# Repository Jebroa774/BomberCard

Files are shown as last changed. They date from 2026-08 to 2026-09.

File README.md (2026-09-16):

# BomberCard V1

<p align="center">
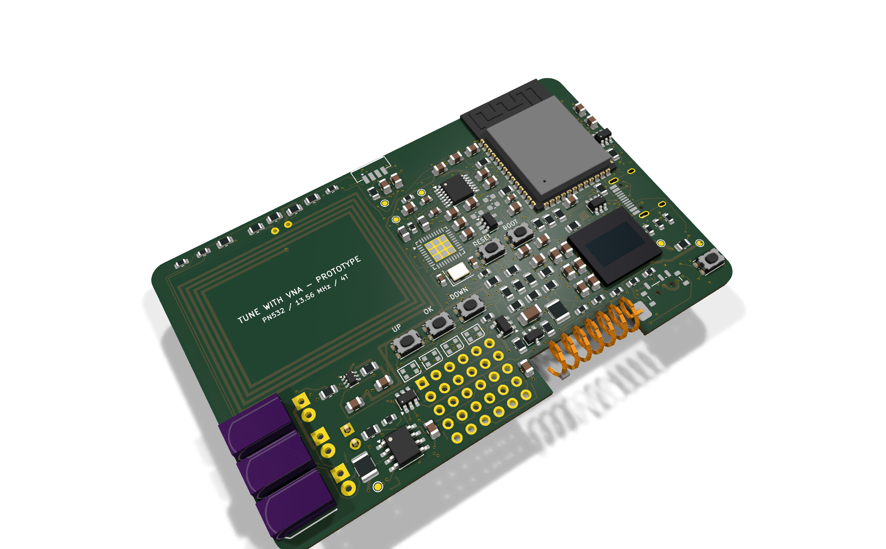
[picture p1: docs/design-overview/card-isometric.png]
BomberCard V1 current KiCad isometric view
  
</p>

BomberCard V1 is an original, credit-card-outline ESP32-S3 field tool with
Wi-Fi/BLE control, NFC, LF RFID, Sub-GHz, infrared, removable storage and a
small local user interface. The hardware is designed around a four-layer PCB,
a single-cell LiPo supply and parts that can be assembled by JLCPCB or fitted by
hand where practical.

> [!NOTE]
> **Proudly vibe-coded.** The project grows through hands-on experimentation,
> rapid idea-driven iteration and AI-assisted engineering. Here, vibe coding
> does not mean blindly trusting generated output: the hardware remains an
> engineering prototype until its schematic, PCB, DRC/DFM results and physical
> measurements have been independently checked.

> [!WARNING]
> **Engineering prototype — not ready to order.** The current authoritative
> board has 33 open connection items. KiCad reports 0 geometric/electrical DRC
> violations; the 7 remaining report entries are footprint-library comparison
> notices. Routing completion, DFM review, RF/LF tuning, sourcing review and
> prototype measurements remain required before fabrication.

## Current hardware

| Area | V1 implementation |
|---|---|
| Controller | ESP32-S3-WROOM-1-N8R2 with native USB, Wi-Fi and BLE |
| 13.56 MHz NFC | PN532 with a project-local 35 x 27 mm four-turn PCB antenna |
| 125 kHz LF RFID | HTRC110 front end with a removable, measurable and tuneable coil |
| Sub-GHz | E07-900MM10S/CC1101 module, tuneable pi network and inboard 868 MHz spring antenna |
| Infrared | Three independent high-power 940 nm emitters plus a 38 kHz receiver |
| Storage and security | microSD, ATECC608C secure element and physical PAIR button |
| User interface | Four RGB LEDs, UP/SELECT/DOWN controls and a firmware-configurable AUX button |
| Sensors | Optional 6-axis IMU, barometer, RTC, fuel gauge and board-temperature monitor |
| Power | USB-C, 1-cell LiPo input, charging/power path, regulated 3.3 V and switchable 5 V |
| Expansion | Protected 2.54 mm breakout matrix with eleven direct expansion GPIOs |

The **ESP32-S3 remains the controller for V1**. The newer ESP32-S31 is being
kept as a possible V2 candidate, but its preliminary hardware ecosystem,
larger WROOM module and immature availability do not justify restarting this
layout.

## Current PCB views

The following images were generated from the current KiCad routing checkpoint.
The hand-fitted IR bodies and spring antenna use approximate preview models;
footprints, courtyards and the PCB outline remain the mechanical references.

<table>
  <tr>
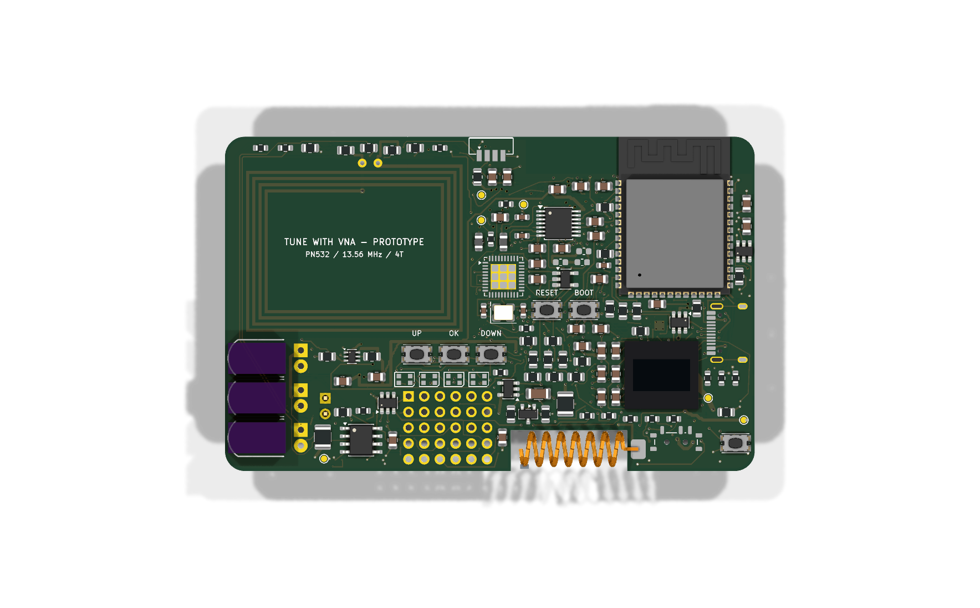
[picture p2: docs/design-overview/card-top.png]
Current PCB top view
    <td align="center"><br><strong>Top</strong></td>
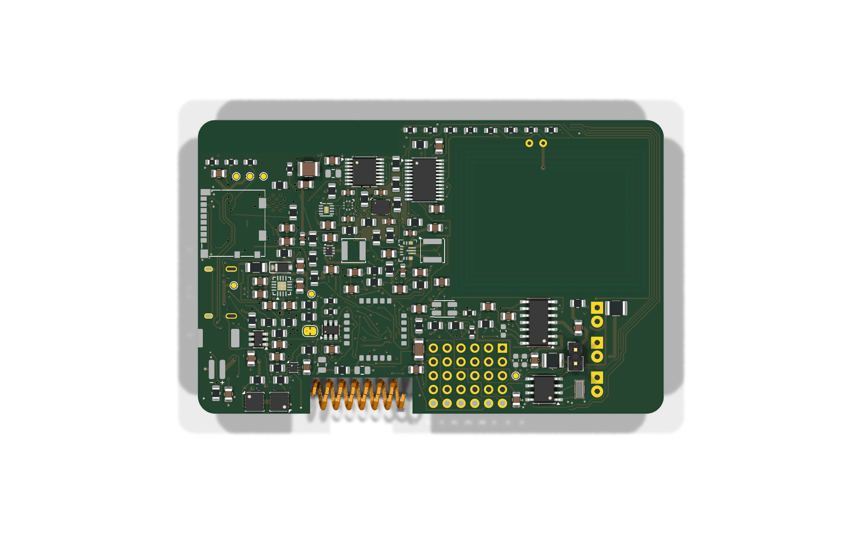
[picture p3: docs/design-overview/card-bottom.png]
Current PCB bottom view
    <td align="center"><br><strong>Bottom</strong></td>
  </tr>
</table>

More layout and enclosure notes are available in the
[design overview](docs/design-overview/README.md). An interactive WebGL view is
available as the
[live BomberCard 3D Viewer](https://jebroa774.github.io/BomberCard/).
Its source is stored in
[`docs/design-overview/viewer.html`](docs/design-overview/viewer.html).

## Mechanical target

- 85.60 x 53.98 mm credit-card outline with rounded corners
- Four-layer, nominal 1.2 mm FR-4 using the JLC04121H-7628 stack target
- 1 oz outer and 0.5 oz inner copper with ENIG finish
- Components on both sides; approximately 8–9 mm provisional assembled height
- Three inboard edge-facing IR emitters and an inboard spring-antenna pocket
- Compact unpopulated 6 x 5 matrix of 30 holes on 2.54 mm pitch
- Initial bring-up quantity: five assembled prototype boards

This is a credit-card-shaped instrument, not a wallet-thickness card. The final
height and enclosure clearances must be verified against received components.

## Engineering status

| Check | Current result |
|---|---:|
| Schematic symbols | 274 |
| Assigned footprints | 267 |
| Named logical nets | 181 |
| Physical PCB nets | 231 |
| ERC | 0 errors / 0 warnings |
| Placed footprints | 264 |
| Routed checkpoint | 4863 track segments / 1019 vias / 24 zones |
| Remaining connection items | 33 |
| Geometric/electrical DRC findings | 0 |
| Footprint-library comparison notices | 7 |

Completed design work includes the full schematic, mechanical placement,
four-layer stack definition, native USB pair, local converter routes, RTC
crystal routes, the provisional Sub-GHz feed/pi network and the via-free
back-side LF RFID analog island. The active PCB work is closing the final 33
routing connections while preserving the current zero-error DRC baseline.

### Before the first PCB order

- Confirm the live JLCPCB stack and recalculate USB/Sub-GHz geometry.
- Review the completed LF/NFC and digital routing against the schematic.
- Finish DRC cleanup, ground stitching and plane review.
- Re-run final KiCad DRC/parity checks from a clean checkout.
- Review every footprint, BOM and placement entry against current supplier data.
- Reconfirm PN532 availability because the part is NRND, and qualify an
  alternative before any production revision.
- Inspect the JLCPCB DFM, BOM and CPL previews and obtain an independent review.
- Tune NFC, LF RFID and Sub-GHz on the assembled prototypes with suitable test
  equipment before treating any RF values as production-ready.

The detailed hand-off state is maintained in the
[work checkpoint](docs/work-checkpoint.md).

## Repository layout

```text
BomberCard/
|-- docs/           Architecture, constraints, checkpoints and current renders
|-- hardware/       KiCad source, local libraries, reports and layout helpers
|-- firmware/       ESP32-S3 firmware source and board configuration
`-- manufacturing/  Fabrication/assembly generation tools and future releases
```

Open `hardware/PocketLab-Card.kicad_pro` in KiCad 10 for the complete project.
The tracked `hardware/PocketLab-Card.kicad_pcb` is the current routing-in-progress
board, not a fabrication release.

## Responsible use

RF, RFID/NFC and infrared functions are intended only for devices, systems,
frequencies, antennas, output levels and duty cycles the operator is legally
permitted to use. Prototype RF performance, electromagnetic compatibility and
regulatory compliance have not yet been verified.

The project is original and does not copy SGP branding, artwork, PCB layout or
firmware.

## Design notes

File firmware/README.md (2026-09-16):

# BomberCard firmware

Buildable ESP32-S3 bring-up firmware for hardware revision 1. It targets the
ESP32-S3-WROOM-1-N8R2 with Arduino-ESP32 3.x and PlatformIO.

## Implemented baseline

- WPA2 Wi-Fi SoftAP, REST API, read-only WebSocket status and mobile web UI
- microSD mount, listing, download, upload, deletion and remount
- safe boot states for CC1101, microSD, IR, RGB, LF RFID and exposed GPIOs
- read-only CC1101 identity, PN532 presence and both I/O-expander probes
- HTRC110 5 V power sequencing, three-wire command transport, configuration
  readback, phase/sampling setup and antenna-failure diagnosis
- ATECC608C wake/presence probe without changing or locking its configuration
- physical PAIR-button gate for a 60-second pairing window
- bounded NEC IR transmission through the three emitters
- 16-sample GPIO9 board-NTC measurement, web status and 80-degree-C thermal
  shutdown of charging and 5-V loads with 70-degree-C release hysteresis

Tag protocol framing/decoding, secure-element provisioning, persistent owner
keys, the phone app, PN532 transactions, CC1101 receive/decoding, IR decoding,
sensor drivers and battery telemetry remain separate follow-up work. In
particular, an open pairing window is not yet an owner lock.

## Build

```powershell
pio run
pio run -t upload
pio device monitor
```

The 2026-08-11 validation used Arduino-ESP32 3.3.8 and WebSockets 2.7.3. The
release build used 49,568 bytes RAM and 1,113,399 bytes application flash.

At boot, USB CDC prints the generated prototype access point credentials and
`http://192.168.4.1/`. The per-device password and boot-session HTTP token are
for local bring-up; they are not a substitute for the later ATECC-backed app
authentication protocol.

## Safety policy

`platformio.ini` enables only bounded IR transmission. Sub-GHz transmission
and arbitrary GPIO outputs stay compiled out. LF RFID powers up only on an
authenticated local request: the 5 V boost is enabled first, then the HTRC110
rail; shutdown happens in the reverse order. HTRC tag writing is not exposed.
The internal NTC blocks new LF/boost/IR requests at 80 degrees C, disables
charging and existing 5-V loads, and releases only the charger below 70 degrees
C. Loads remain off until the app explicitly requests them again.
An open or shorted divider is treated fail-safe like an overtemperature event.

## HTTP interface

Read-only endpoints include `/healthz`, `/api/config`, `/api/status`,
`/api/hardware`, `/api/gpio`, `/api/files` and `/api/file`.

Mutations require the current `X-BomberCard-Token` header:

| Method | Path | Purpose |
|---|---|---|
| `POST` | `/api/lf/power?enabled=1` | Sequence LF 5 V and run the HTRC self-test |
| `POST` | `/api/lf/diagnose` | Repeat configuration, phase and antenna checks |
| `POST` | `/api/security/pairing-window` | Open 60 s only while PAIR is held and ATECC is present |
| `POST` | `/api/ir/tx?address=0&command=0&repeats=0` | Send one bounded NEC frame |
| `POST` | `/api/sd/remount` | Remount microSD |
| `POST` | `/api/upload?path=/uploads/name` | Upload a file |
| `DELETE` | `/api/file?path=/uploads/name` | Delete a file or empty directory |

## First-board checks

- U9/TCA9535 at `0x20`, U18/TCA9534 at `0x21`, PN532 at `0x24`
- ATECC608C-SSHDA default address `0x60`; keep it unprovisioned until the app
  key format, recovery process and production lock manifest are reviewed
- U18 P4 is `LF_RFID_EN`; boot latch keeps LF 5 V and boost off
- LF pins: GPIO18 SCLK, GPIO21 DOUT, GPIO35 DIN; GPIO38 is active-low PAIR
- GPIO9 is the internal board-temperature ADC and J5 pin 7 is probe-only
- HTRC110 page readback, `ANTFAIL`, measured phase and tuned external coil
- CC1101 identity and shared-SPI chip-select idle levels

`include/board_pins.h` mirrors `docs/pinout.md`.

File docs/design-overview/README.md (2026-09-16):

# BomberCard design overview

These KiCad renders show the current routing checkpoint, not the final
fabrication appearance. Placement is complete, but 33 connection items remain
open. The IR bodies and spring antenna use approximate mechanical preview
models; the footprint courtyards and board outline remain the manufacturing
references. RF stitching, several sensitive routes and final enclosure
clearances are still open.

## Current views

Current isometric view

| Top | Bottom |
|---|---|
| Current top view | Current bottom view |

## Interactive 3D viewer

Open [viewer.html](viewer.html) through GitHub Pages or a local static web
server to rotate, zoom and inspect the exported board model. The viewer loads
[`pocketlab-card.glb`](pocketlab-card.glb), generated directly from the current
KiCad PCB. A few footprints have no installed upstream 3D model; their pads and
board copper remain present in the export.

The ESP32-S3-WROOM-1-N8R2 shown here remains the V1 controller. ESP32-S31 is a
future V2 candidate and is not part of this PCB revision.

## Visible front-side areas

| Area | Current contents | Enclosure / artwork guidance |
|---|---|---|
| Upper-left | 35 x 27 mm NFC loop | Good visual focus for a printed logo or non-metallic graphic. Do not add metal foil, magnets, conductive paint, screws or a battery over the loop. |
| Upper-right | ESP32-S3 module and PCB antenna | Plastic and ordinary non-conductive ink only around the antenna end. No metal bezel, shield, battery or cable directly over it. |
| Top edge | Side-view 38 kHz IR receiver | Keep a small dark IR-transparent window over its optical face. The body and pads remain inside the card outline. |
| Lower-right | AUX/PAIR buttons, main switch and USB area | Provide switch openings and USB access. The battery connector is on the back; the removed OLED area is routing and enclosure reserve. |
| Lower-middle | Four 2-mm RGB LEDs, compact UP/OK/DOWN buttons, and adjacent labeled RESET/BOOT service buttons | Use four small windows or one frosted light bar. A three-position membrane can cover the navigation row; keep RESET/BOOT accessible through small service holes. |
| Left short edge | Three flat TSAL6200 IR emitters | All optical faces sit 0.5 mm inside the edge and the lowest body clears the rounded corner. Each vertical 2.54-mm pad pair gives both leads one common 90-degree bend line. Provide one clear opening across the three lenses. |
| Lower edge | Compact 6 x 5 Dupont hole matrix | All 30 connections retain 2.54 mm pitch. Individual Dupont leads and breakaway strips fit; one monolithic 2 x 15 housing does not. |
| Lower-right pocket | 868 MHz helical spring antenna | The 17.3 mm cylindrical spring lies inside an 18.8 x 6.58 mm recess. Its right end is the only electrical solder point; a small nonconductive epoxy or neutral-cure silicone bridge anchors the free left end to the upper FR4 pocket wall. Never solder or ground that free end. Neither spring nor pad exceeds the original card envelope. |

## Back side

The back carries power conversion, protection, sensors, RTC, I/O expanders,
the two-part board-temperature divider beside the 5-V converter,
the removable 125 kHz coil connector, the via-free HTRC110 analog island and
the Sub-GHz module. It is not a flat cosmetic surface. The large apparently
empty region opposite the NFC loop must also remain free of metal and major
components; it is an RF keepout, not spare battery space.

## Practical styling directions

1. **Exposed technical card:** black solder mask, white silkscreen, visible NFC
   loop and translucent RGB light bar.
2. **Thin two-piece shell:** solid front graphic with windows only for buttons,
   RGB, IR and connectors; the PCB remains serviceable from the back.
3. **Instrument style:** label the four RGB/button positions as modes, use the
   NFC loop as a framed graphic field and use RGB patterns for compact status.

The bare PCB is 85.60 x 53.98 x 1.2 mm. The final assembly is not wallet-flat:
without the optional Dupont header, allow roughly 8-9 mm overall until exact
received-part and enclosure measurements replace this provisional envelope.

## Verification status

The current placement and retained routing pass the scripted component/keepout
audit. Schematic parity and ERC are clean. KiCad DRC reports 0
geometric/electrical violations and 7 footprint-library comparison notices.
The 33 unconnected items are the explicit routing blocker, so this revision
must not be sent to fabrication yet.

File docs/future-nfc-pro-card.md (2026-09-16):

# Future concept: PocketLab NFC Pro

Status: parked for later; not part of the current BomberCard V1 routing.

## Decision

Build the maximum-performance NFC system as a separate card. Do not add it to
the current multifunction BomberCard. A dedicated board gives the antenna,
matching network, sensitive analogue paths and real-time processing enough
space and avoids interference from Wi-Fi, displays, IR and the other power
domains.

The preferred first board is NFC-only at 13.56 MHz. If advanced 125/134.2-kHz
LF RFID is wanted later, implement it as a second sister card with its own coil
and analogue frontend. Combining both antennas on one credit-card PCB is
theoretically possible, but would compromise the performance and tuning of both
systems.

## Proposed NFC Pro architecture

```text
USB-C / optional battery
          |
    power management
          |
     main real-time MCU <-> FPGA <-> NFC frontend <-> tunable matching <-> large HF loop
          |                 |              |
   flash / microSD      raw capture     RF measurement path
          |
    secure element
```

Preferred laboratory-oriented implementation:

- ST25R3916B high-performance 13.56-MHz frontend for NFC-A/B/F/V, automatic
  antenna tuning and transparent/stream modes.
- High-performance real-time MCU, with the i.MX RT1170 family as the initial
  candidate.
- FPGA for cycle-accurate modulation, demodulation, timestamping, raw-frame
  capture and experimental authorised emulation.
- Secure element for owned test credentials, device identity and signed
  firmware.
- Large perimeter PCB antenna with a copper-free keepout on every layer.
- Switchable C0G matching bank, DNP tuning positions, VNA pads and field/current
  measurement points.
- U.FL or SMA option for interchangeable external antennas and a separate
  receive/sniffer connection.
- USB high-speed streaming, microSD and QSPI flash for long RF captures.
- Likely six-layer central digital island; antenna area kept free of planes and
  unrelated routing.

Alternative product-oriented implementation:

- PN7642 when maximum standards integration, strong reader operation and
  conventional card emulation are more important than raw waveform access.
- It integrates a Cortex-M33, hardware security, broad NFC/MIFARE protocol
  support and a high-power transmitter.

## Possible LF RFID sister card

- Separate large 125/134.2-kHz coil.
- Half-bridge or full-bridge transmitter with controlled current.
- Low-noise, variable-gain receive chain plus comparator and raw ADC path.
- FPGA support for ASK, FSK and PSK capture/generation.
- Switchable resonance capacitor bank and connector for external coils.
- Shared host software and USB protocol with NFC Pro, but no shared antenna.

## Physical direction

- NFC-only can realistically retain the 85.60 x 53.98-mm card outline.
- The assembled device will be thicker than a payment card because of USB,
  connectors, power components and test interfaces.
- A combined maximum-performance NFC+LF instrument should instead use two
  cards or a larger enclosure; fitting both onto one card is not the preferred
  architecture.

## Scope boundary

The intended scope is authorised RF/protocol analysis, antenna development,
reading supported tags and emulating credentials owned for testing. The
hardware does not recover non-exportable keys from secure MIFARE DESFire/Plus
credentials and does not make exact cloning of protected credentials possible.

## Resume point

When this project is resumed:

1. Freeze the use cases: reader range, sniffing, card emulation and required
   NFC standards.
2. Choose between ST25R3916B plus FPGA (laboratory flexibility) and PN7642
   (integrated protocol/product path).
3. Fix the antenna outline and target inductance before placing electronics.
4. Create the schematic, RF matching worksheet and power budget as a new
   project rather than modifying BomberCard V1.

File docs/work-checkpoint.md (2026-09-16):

# Work checkpoint — 2026-09-16

## Current authoritative routing state — 2026-09-16

- The authoritative board is `hardware/PocketLab-Card.kicad_pcb`.
- KiCad connectivity reports **33 open connection items**.
- A fresh KiCad 10 DRC run reports **0 geometric/electrical violations** and
  **7 footprint-library comparison notices**.
- The board currently contains 264 footprints, 4,863 track segments, 1,019
  vias and 24 zones.
- Current top, bottom and isometric renders plus an interactive GLB viewer are
  stored under `docs/design-overview/`.
- This is a safe routing checkpoint, not an order-ready fabrication release.

The dated notes below document older routing phases and are retained as design
history; their connection and DRC counts are no longer the current status.

## Routing/DRC continuation — 2026-08-30

- The active board is `hardware/PocketLab-Card-routing-working.kicad_pcb`.
  It contains 2,843 track segments, 575 conventional through-vias and 23
  zones. KiCad connectivity reports 0 open connection items.
- This continuation reassigned ten reviewed long signal segments between the
  two inner copper layers. Every accepted change was tested separately and in
  combination; no track coordinates, footprints, vias or net assignments were
  changed.
- One additional USER_BUTTON_A_N diagonal was replaced by a four-segment,
  obstacle-aware path on the same inner layer. This reduced its local median
  from 20 to 18 findings without adding a via or an open connection.
- The latest continuation rerouted EX4, EX5, CHG_TS_FIXED, GPIO8_MCU and
  SD_DETECT_N, moved AUX5_FAULT_N and BAT_SENSE vias with layer-matched
  fanouts, and reassigned CHARGER_CHG_N from L2 to L3. All accepted edits
  retain 0 open connection items and use only conventional through-vias.
- Three final full-board DRC runs reported 1,162, 1,164 and 1,166 findings.
  The saved median report has 502 clearance, 4 copper-edge, 201 hole-clearance,
  199 shorting, 106 solder-mask bridge and 147 crossing findings. Crossing
  counts are not fully deterministic between
  otherwise identical KiCad CLI runs, so local repeated checks are used when
  accepting a routing-layer change.
- The stale AE1 NFC-loop library rule now matches the intentional board
  keepout and no longer causes a footprint mismatch. The remaining comparison
  findings include project-specific board geometry on U1/U3 plus current
  KiCad standard-library differences; they are documented rather than
  overwritten blindly.
- This is a saved engineering checkpoint, not an order-ready fabrication
  release.

## Active PCB routing state — 2026-08-21

- Work has resumed on the PCB only; firmware and app work remain deferred.
- The 2026-08-16 continuation corrected the physical internal-contact
  semantics of the six KMR2 switches and the continuous J1/J2 shell contacts.
  This removed one false ratsnest item without adding copper. J2 was also
  shifted 0.175 mm inward; all ten microSD copper-to-edge findings are gone
  while the adjacent B.Cu ground track retains exactly 0.20 mm clearance.
- U2.5 and U2.8 now share a short, via-free 0.15-mm NFC_DVDD escape on F.Cu.
  The former long U2.3 ground branch was folded directly into the exposed GND
  pad, one redundant west-side GND via was removed, and the retained plane via
  moved 0.20 mm right / 0.10 mm up into a clearance-clean site. U2.3, U2.7 and U2.41 remain
  explicitly connectivity-checked to GND.
- Current local checkpoint saved on 2026-08-21 Europe/Berlin; the
  authoritative PCB, DRC/ERC reports and progress documentation are in sync.
  No commit or remote push was requested in this continuation.
- LF RFID shares the existing SPI SCK/MOSI/MISO bus. U21 remains the
  partial-power-down-safe SN74LV125ATPWR (LCSC C2675655), and U22 remains the
  LF_RFID_EN-controlled SN74LVC1G126DBVR (LCSC C7834). U21 channels 2 and 4
  translate SCK and MOSI; the unused channel input/OE pairs are grounded and
  their outputs are NC. This avoids back-powering or driving an unpowered LF
  domain while giving all seven U21 GND pads short inner-plane connections.
- Six global LF/shared-SPI data paths are routed and connectivity-checked:
  SPI_SCK, SPI_MOSI, SPI_MISO, LF_SCLK_5V, LF_DIN_5V and LF_DOUT_5V.
  The LF_RFID_EN U22 enable endpoint is now complete. A redundant +3V3 fanout
  via in the dense PN532/U22 field was removed, R109 now joins the retained
  +3V3 branch directly, and U22.1 reaches the existing LF-enable trunk through
  a 0.45/0.20-mm via and a reviewed 0.20-mm L3 route. L2 remains plane-only;
  `scripts/route_lf_enable.py` reproduces and connectivity-checks this stage.
  The low-current LF_5V branch from the existing distribution via C515 to U21
  is also complete, with a reviewed 0.39-mm TSSOP neckdown.
- The dense U8/U11 sensor corridor is now reworked. U8 SCL reaches U1.6
  through two standard 0.45/0.20-mm through-vias and a short L3 crossing;
  U8 SDA reaches U11.4 directly on B.Cu. `FG_ALERT_N` and `SPI_MOSI` were
  rerouted around the corridor, and the local U11.3/U11.5 ground branches were
  restored. `scripts/route_i2c_sensor_corridor.py` reproduces and checks all
  six affected endpoint pairs while L2 remains ground-only.
- The dense-plane cleanup is complete. All GND and +3V3 islands are now
  closed, including the difficult U2.40, C704 and microSD J2.4 fanouts. U2.40
  uses a reviewed local reroute of LF_SCLK_5V/LF_DIN_5V; C704 is connected on
  B.Cu without a via below U21, and J2.4 reaches the L3 +3V3 plane through a
  clearance-checked 0.45/0.20-mm via.
- The accepted charger and battery-protection power stages are complete.
  VBUS_FUSED now joins F1, D101,
  C106, C103, U5.13 and U16.5 with 0.50/0.60-mm copper and one ordinary
  0.80/0.40-mm via. Both U5 CELL_POS pins join C121/C104 through short local
  neckdowns; the main CELL_POS route then runs at 0.80 mm to J4.1 and reuses
  one capacitor via. CELL_NEG leaves J4.2 without via-in-pad, crosses on F.Cu
  outside the connector pad and reaches Q2 with a reviewed local neckdown.
  BAT_FET_MID joins Q2/Q3 at 0.80 mm, and BAT_COUT plus the U14 CELL_NEG sense
  return complete the local battery-protection block. VSYS now joins U5, U6,
  U7 and the local bulk capacitors through a reviewed B.Cu corridor. R129 is a
  hand-friendly 0805 zero-ohm SPI_MOSI crossover that preserves the solid L2
  GND plane and the protected L3 power corridors.
  Both USB-C VBUS contact groups now reach F1 through 0.30-mm F.Cu pin escapes,
  two 0.70/0.35-mm vias and a short 0.20-mm shield-corridor neck that widens
  immediately to 0.50/0.60 mm. `+5V_RAW` and `+5V_AUX` are now fully connected
  through two narrow, higher-priority L3 corridors; all other 5-V trunks are
  complete as well. L2 remains an uninterrupted GND return plane. L3 retains
  the protected power polygons and may also carry ordinary low-speed digital
  traces outside +5V_RAW/+5V_AUX, RF, USB, NFC and LF analogue keepouts.
- The authoritative PCB now contains 1889 track segments, 343 vias and 23
  zones. The current ratsnest contains 138 open connection items. GND, +3V3,
  +5V_RAW and +5V_AUX are all fully connected.
  Accepted DRC-neutral additions include I2C_SDA, EX0/EX1/EX4 interrupt,
  NFC_I0, SUBGHZ_GDO2, AUX5_EN, I2C_SCL_HDR, SPI_SCK_HDR, GPIO44_MCU, BOOT_N,
  USER_BUTTON_B_N, CHG_DISABLE, USER_BUTTON_SELECT_N, SUB_CS_N, SPI_SCK,
  SD_DETECT_N and AUX5_FAULT_N islands. Both PN532 crystal pins and their
  load-capacitor branches are complete. The two local matching-to-loop paths
  and both external loop feeds are routed through the intended NFC keepout
  corridors; the latter use two ordinary vias and short L3 signal sections.
  The three high-output IR LEDs now share a complete 0.50-mm common-cathode
  route along the short board edge.
- The short PN532 `/NFC_TX2_F` matching branch from L302.2 to C309.1 is now
  complete with five locked 0.15-mm F.Cu segments and no via. Its narrow
  corridor retains 0.25 mm to both C301 and the reviewed LF_DIN_5V crossing;
  `scripts/route_nfc_tx2_matching.py` reproduces and checks this connection.
- The microSD `/SD_CS_DEV` leg now connects U19.1 to J2.2 through one local
  0.45/0.20-mm via. The U19.2 GND escape was shifted toward the card edge while
  retaining the same plane via; `scripts/route_sd_cs_socket.py` reproduces and
  checks both endpoint groups.
- The ESP32 `/SPI_MOSI` pad U1.19 now joins the existing U21/R129 shared-bus
  group through eight locked 0.15-mm F.Cu/B.Cu segments and one 0.45/0.20-mm
  via. `scripts/route_spi_mosi_mcu.py` reproduces and checks the endpoint pair.
- The microSD resistor-side `/SPI_MOSI` pad R511.1 now joins that shared group
  through six locked 0.15-mm L3 segments, one short F.Cu escape and one
  0.45/0.20-mm via. `scripts/route_spi_mosi_sd_resistor.py` reproduces the
  route and checks R511.1 against R129.2 after the plane refill.
- The USB-C `/USB_CC1` receptacle pad J1.A5 now reaches R101.1 through ten
  locked outer-layer segments and one 0.45/0.20-mm via. U16.4 joins J1.A5
  through nine locked 0.20-mm F.Cu segments with no additional via, leaving
  all three CC1 pads in one group. `scripts/route_usb_cc1_resistor.py` and
  `scripts/route_usb_cc1_esd_branch.py` reproduce the two reviewed stages.
- The UP-button `/USER_BUTTON_A_N` contact SW3.1 now reaches R608.1 through
  ten locked 0.15-mm segments, two 0.45/0.20-mm vias and a short reviewed L3
  crossing. U18.11 remains the second net group;
  `scripts/route_user_button_a_pullup.py` reproduces the accepted geometry.
- The back-side `/CELL_POS` monitor input U8.3 now reaches local capacitor
  C120.1 through four locked, via-free 0.15-mm B.Cu segments;
  `scripts/route_cell_pos_monitor.py` reproduces and checks this endpoint pair.
- CELL_NEG test point TP102 now sits directly on the existing front-side
  battery-negative trunk at 103.85,65.75 mm. This closes its isolated group
  without adding copper; `scripts/place_tp102_cell_neg.py` reproduces the
  locked placement and is idempotent.
- CELL_POS test point TP101 now sits on the existing 0.8 mm front-side trunk
  junction at 98.10,62.20 mm. This closes its isolated group without adding
  copper while keeping the probe pad clear of the connector and resistor
  courtyards; `scripts/place_tp101_cell_pos.py` reproduces the locked,
  idempotent placement.
- VBUS_USB test point TP105 now sits on the back at 99.00,50.40 mm, directly
  on the existing 0.5 mm USB input trunk. The opposite side of the USB-C
  receptacle remains free of back-side component courtyards, so the probe pad
  stays accessible; `scripts/place_tp105_vbus_usb.py` reproduces the locked,
  idempotent placement.
- The protected `/GPIO43` output R718.2 now reaches expansion-header pad J5.11
  through three locked 0.15-mm L3 segments and one 0.45/0.20-mm tented via;
  `scripts/route_gpio43_header.py` reproduces and checks this endpoint pair.
- The protected `/SPI_MISO_HDR` branch now joins R734.2 to J5 ESD-array pad
  U25.1 through eleven locked 0.15-mm F.Cu/L3 segments and two tented
  0.45/0.20-mm vias; `scripts/route_spi_miso_header_esd.py` reproduces and
  checks the endpoint pair while leaving the L2 GND plane signal-free.
- The PN532 `/NFC_TX1` output U2.4 now reaches matching inductor L301.1 through
  two F.Cu escapes, three locked 0.20-mm L3 segments and two tented
  0.45/0.20-mm vias. Two local LF clock/data jogs preserve those neighboring
  nets while opening the conventional through-via corridor;
  `scripts/route_nfc_tx1_driver.py` reproduces and checks the endpoint pair.
- The OLED `/OLED_VCC` supply now joins C615/C616 to J8.16 through one
  0.45/0.20-mm tented via, a 0.15-mm L3 crossing and a short F.Cu escape. The
  neighboring `/OLED_C1P` corridor is narrowed locally to the project minimum,
  and one short `+5V_AUX` L3 bridge keeps all five AUX5 pads in one plane group.
  `scripts/route_oled_vcc.py` reproduces and checks all three affected nets.
- Schematic/PCB/design-netlist parity passes, every new route passes explicit
  endpoint connectivity checks, and ERC reports 0 errors / 0 warnings. DRC
  reports 16 known non-release findings: 8 existing clearance findings, one
  J4 copper-to-edge finding, six reviewed footprint-library findings and one
  positionless B.Cu copper-sliver warning created by plane refill. The project
  minima are now 0.15-mm track, 0.45-mm via and 0.20-mm drill; critical power,
  USB, NFC, LF and Sub-GHz nets retain their stricter custom rules. No new
  routing clearance, short, dangling-track or power violation is present.
- This is a reproducible routing checkpoint, not an order-ready board.

## Saved state

- ESP32-S3-WROOM-1-N8R2 remains the V1 controller. ESP32-S31 was reviewed as a
  possible future V2 option but is not being introduced into this revision;
  changing to its larger, preliminary WROOM ecosystem would restart placement,
  routing and firmware validation without improving a current V1 requirement.
- Generated schematic: 274 symbols, 267 footprints and 181 named logical nets;
  the current PCB contains 231 physical nets, including three unique NC nets.
- GNSS hardware has been removed. U4 is now HTRC110 125-kHz LF RFID with
  switched 5 V, level translation, external 4-MHz clock and removable coil.
- ATECC608C-SSHDA-T, decoupling and the dedicated SW6 PAIR button are captured.
- U24/U25 add low-capacitance shunt protection to every exposed J5 I2C/SPI
  line. Direct GPIO and expander pins retain their existing series protection.
- TP601 and TP701-TP703 were removed: the last RGB output is intentionally NC.
  BMI270 retains both interrupt lines; BMP390 pin 7 is intentionally NC and
  pressure data remains available by I2C polling.
- R736/RT701 add a 10-kohm B3950 board-temperature divider on GPIO9 in the
  former 4 x 4 mm back-side pocket. J5 pin 7 is now probe-only through R714;
  eleven direct expansion GPIOs remain.
- Stale GNSS DNP rules were removed from the manufacturing exporter; its safety
  defaults now match the NFC, Sub-GHz and LF tuning footprints in this design.
- Repository cleanup removed the superseded placement render, empty capture-target
  sheets, generated PCB/autorouter intermediates and their duplicate DRC reports.
  These staging files are reproducible from `hardware/scripts` and are now ignored;
  the main schematic and `PocketLab-Card.kicad_pcb` remain authoritative.
- The placement builder fits all 267 footprints (131 front, 136 back) without
  unapproved courtyard, keepout or board-inset collision.
- The authoritative routed checkpoint contains 130 front and 137 back
  footprints. The one-part-per-side difference from the regenerated placement
  donor is limited to a generic unrouted packing slot; all 267 references exist.
- U4 and its LF resonance, current-limit, RX, oscillator and coil-interface
  parts now form one compact back-side analog island beside J3. C506/C507/C508
  are aligned as a straight tuning bank; C507/C508 remain DNP options.
- `LF_TX1`, `LF_TX2`, `LF_ANT_A`, `LF_ANT_B`, `LF_TAP`, `LF_RX`, `LF_CEXT`,
  `LF_QGND` and `LF_CLK_4M` are completely routed on B.Cu with no vias.
  The front-side U17 support island and its LF 5-V distribution to U4, Y501
  and C513 are also routed. A narrowly scoped U17 pin-escape rule permits a
  0.20-mm SOT-23 neckdown; three ordinary tented through-vias carry LF 5 V.
- The placement generator reserves the LF support route corridor so future
  regenerations cannot silently pack unrelated parts into it. The LF analog,
  placement-merge and support routes are reproducible with the three dedicated
  scripts in `hardware/scripts`.
- The solid L2 GND plane and mixed-power L3 plane regenerate successfully;
  the L3 +5V polygons are protected from ordinary-signal routing.
- The PCB stack is now the nominal 1.2-mm, four-layer
  `JLC04121H-7628` target with 1-oz outer / 0.5-oz inner copper and ENIG.
  Confirm the live factory stack before freezing USB and RF widths.
- Routing has started. The main PCB contains the guarded digital fanout and
  DRC-clean local routes for U6_L1, U6_L2, U7_SW, RTC_OSCI and RTC_OSCO. U6
  input/output power, U7 input/output power, U7 feedback and the low-current
  5-V feedback sense branch are now also routed. The nearby IR branch was
  rerouted around Y701, and R405 now faces U3 -> antenna. CC2 and the provisional
  Sub-GHz feed are also complete. The subsequent split-5V and dense-plane
  stages formed the earlier 1214-segment checkpoint; the current authoritative
  board has advanced to 1889 segments, 343 vias and 23 zones.
- Two named B.Cu rule areas limit U7's unavoidable 0.20-mm power-pin neckdowns
  to the package exits and the reviewed Kelvin/sense corridor; the power rails
  widen to 0.50 mm outside those areas.
- The accepted stage-5 pass completes VSYS without inner-layer signal copper.
  R129 (C17477) splits SPI_MOSI through a real 0805 series crossover, and the
  corridor uses a documented 0.30-mm VSYS neck only where required.
- The accepted stage-6 pass completes the local USB-C VBUS-to-F1 connection.
  Its two connector escapes and shield-corridor neck are bounded by three named
  rule areas; all longer input-current sections use 0.50/0.60-mm copper.
- R201/R202 are now vertical, side-by-side 0805 parts. The native USB pair is
  fully routed from U1 through both 22-ohm resistors and U16 to all four J1
  A6/B6/A7/B7 data pads. The MCU side is via-free; the connector bridge uses
  five 0.50/0.30-mm vias and a local 0.15-mm fine-pitch clearance area.
- U16 moved 0.55 mm inward and R102 is now a fixed front-side 0805 below the
  USB data crossover. J1 B5, R102, its local ground return and the U16 pin-6
  protection branch are routed. CC2 changes layer with two standard
  0.50/0.30-mm through vias and has no signal trace on L2/L3. The narrowly
  scoped 0.20-mm C103/C104 escape rule leaves every other power-pair clearance
  at 0.25 mm. R101 remains a fixed 0805 on the back beside the right edge.
- The Sub-GHz pi network is now routed at the provisional 0.36-mm width. C404
  is perpendicular to the feed, `/SUBGHZ_RF_MOD` stays on B.Cu and
  `/SUBGHZ_RF_ANT` makes exactly one 0.60/0.30-mm transition to F.Cu before the
  spring pocket. The front trace stays outside the antenna notch. The obsolete
  `/OLED_VCC` autorouter path through C404's corrected ground-shunt position was
  removed and has since been replaced by the reviewed local OLED route above.
- SW3/SW7/SW4 now form a compact, labeled UP/OK/DOWN row using the same
  KMR221GLFS footprint as RESET/BOOT. R607 is the SELECT pull-up; U9/P07 is the
  SELECT input and BMP390 INT is NC. PAIR remains a separate security button.
- SPI_SCK, SPI_MOSI, SPI_MISO, I2C_SCL, GPIO44_MCU, NFC_DVDD, the three user
  button nets, IR_LED_A1, IR_LED_K, GPIO43, NFC_LOADMOD, NFC_RESET_N,
  I2C_SDA, PAIR_N, SPI_MOSI_HDR, SPI_SCK_HDR, LF_DOUT_5V and OLED_VCC
  autorouter copper was removed as complete nets where it crossed the accepted
  USB/button/LF placement. This describes the earlier cleanup; several of those
  islands have since been rerouted with the guarded deterministic router. The
  remaining items stay in the ratsnest without dangling copper stubs.
- The final saved KiCad checks pass schematic/PCB parity and ERC with 0 errors /
  0 warnings. DRC reports 16 known non-release findings: 8 clearances, one J4
  copper-to-edge finding, six local footprint-library comparison warnings and
  one positionless B.Cu copper-sliver warning. There are 138 open connection
  items, so this remains only a routing checkpoint.
- Firmware remains at the preceding two-button checkpoint by explicit project
  priority; no firmware file was changed for the new SELECT hardware. That
  previous ESP32-S3 build provides LF power sequencing,
  HTRC110 configuration/phase/antenna diagnostics, ATECC presence detection,
  a physical 60-second pairing gate, web control, microSD, bounded NEC IR and
  board-temperature readout/80-degree-C shutdown with 70-degree-C hysteresis.
- Secure-element zone locking, persistent owner keys and the phone app are not
  implemented. No irreversible eFuses or ATECC locks have been applied.

## Next engineering steps

1. Reroute the remaining digital/control nets, including the short U24/U25
   clamp branches, then hand-route the dense ESP_EN, BMI/IO-expander and
   microSD signal corridors that the guarded router correctly skips. Refill
   planes after each accepted batch and close all 138 ratsnest items.
2. Complete the PN532 DVDD and TX matching network with reviewed short RF
   paths; preserve the antenna keepout and tune the populated V1 board.
3. Confirm the live `JLC04121H-7628` data and recalculate the stack-dependent
   USB and provisional 0.36-mm Sub-GHz geometry. Retune the assembled pi
   network before treating the RF path as production-final.
4. Run full KiCad DRC, schematic/PCB parity, independent footprint review and
   JLCPCB DFM/BOM/CPL preview.
5. Assemble a small bring-up batch; current-limit first power-up and measure
   every rail before fitting the external coil.
6. Measure the real coil, choose C506/C507/C508, check HTRC phase/ANTFAIL,
   current, voltage and read range.
7. Keep firmware/app work deferred until the PCB routing and manufacturing
   package are complete; then update the input map for UP/OK/DOWN before any
   ATECC provisioning or locking work.

This checkpoint is not an order-ready fabrication release.

## Paused PCBA/layout work (2026-08-17)

Work was paused at the user's request after the first direct-assembly and
compact-layout pass.  The authoritative `hardware/PocketLab-Card.kicad_pcb`
remains the last promoted board and is intentionally not replaced by an
unfinished candidate.

- All 237 populated BOM rows now have an LCSC identifier in the generated
  design data.  Safe commodity passives are assigned smaller 0402/0603
  packages; power, pulse, RF and reviewed crossover parts remain larger where
  their electrical or layout margin matters.
- The through-hole, hand-bent TSAL6200 emitters and the larger user switches
  have direct-assembly SMD replacement footprints.  Their source footprints,
  generator policy and migration/routing helpers are preserved in this branch.
- The best preserved routing candidate is
  `hardware/checkpoints/PocketLab-Card-pcba-routing-wip.kicad_pcb`.  It includes
  the accepted NFC_I0 and SPI_MISO repairs and one +3V3 stitching via.
- Its last full project-context DRC recorded 46 rule findings and 158 open
  connection items.  The higher finding count than the authoritative board is
  primarily the honest result of checking the migrated fine-pitch/custom
  footprints in full project context; it is not a release result.
- A subsequent compact-cleanup script and narrowed custom-clearance rules are
  saved but deliberately not executed/accepted after the pause request.

Resume from the checkpoint candidate, run the compact repair on a new copy,
compare DRC and connectivity, and only then promote a verified candidate to the
authoritative PCB.

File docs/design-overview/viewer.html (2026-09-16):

# BomberCard V1 — interactive PCB model

Drag to rotate, scroll or pinch to zoom, and double-click to reset the view.

KiCad routing checkpoint · 33 open · 0 real DRC errors

Generated from PocketLab-Card.kicad_pcb. Engineering prototype — not ready for fabrication.

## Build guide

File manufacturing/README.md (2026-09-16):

# BomberCard manufacturing handoff

This directory contains the reproducible KiCad 10 export pipeline. Generated
files are intentionally ignored by Git; reviewed release archives are created
as `manufacturing/BomberCard-<release>.zip`.

> **Current status:** `hardware/PocketLab-Card.kicad_pcb` is still marked as a
> placement/routing draft. It is not order-ready. The exporter runs ERC and DRC
> and will currently stop before creating Gerbers. Do not upload the old board
> merely because KiCad can display it.

## Run the checks and export

Run from the repository root with KiCad 10 installed:

```powershell
# Reports and release gates only
powershell -ExecutionPolicy Bypass -File .\manufacturing\scripts\export_release.ps1 `
  -ReleaseName v1-proto -ChecksOnly -Force

# Complete fabrication handoff after every release gate passes
powershell -ExecutionPolicy Bypass -File .\manufacturing\scripts\export_release.ps1 `
  -ReleaseName v1-proto -Force

# PCBA handoff: additionally require Manufacturer, MPN and LCSC for every CPL row
powershell -ExecutionPolicy Bypass -File .\manufacturing\scripts\export_release.ps1 `
  -ReleaseName v1-proto -RequireCompleteProcurement -Force
```

If `kicad-cli` is not on `PATH`, the script finds the normal KiCad 10 Windows
installation. A nonstandard installation can be supplied with
`-KiCadCli 'C:\path\to\kicad-cli.exe'`. Releases must be made from a clean Git
working tree. `-AllowDirty` exists only for local draft checks and must not be
used for an ordered revision.

The pipeline performs these steps in order:

1. KiCad ERC, including all severities in `reports/erc.json`.
2. KiCad DRC with zone refill in memory and schematic/PCB parity checking.
3. A release gate that rejects ERC/DRC errors, every schematic-parity mismatch,
   a dirty source tree, and the explicit placement-draft marker.
4. Master and JLCPCB BOMs, JLCPCB-format CPL, manual-assembly list and a separate
   procurement-gap report.
5. Four copper Gerbers, masks, paste, silkscreen and `Edge.Cuts`; separate PTH/
   NPTH Excellon drills and a drill map.
6. IPC-D-356 netlist, board statistics, source snapshots, SHA-256 manifest and a
   release ZIP plus its checksum.

Warnings remain visible in the JSON reports but do not automatically disappear
or become approvals. Review every warning before ordering. PCB/schematic parity
is deliberately stricter: any mismatch blocks the archive even if KiCad labels
it a warning.

## DNP and assembly data

The exporter builds one effective do-not-populate list from every truthy `DNP`
field in the raw KiCad schematic BOM plus a safety-default list. Truthy values
include `true`, `yes`, `1`, `dnp` and `x`. It enforces the resulting list
independently of PCB-footprint DNP flags, so a missing board flag cannot put an
optional part back into either the JLC BOM or CPL.

The safety defaults are:

- `C109`: optional VSYS bulk capacitor; populate only after a stability and
  transient test shows it is required and safe.
- `C310`, `C311`, `C312`: NFC matching options; leave open until the real PCB
  antenna has been measured and matching values have been selected.
- `C403`, `C404`: Sub-GHz pi-match shunt options; leave open until the assembled
  RF path and spring antenna have been measured.
- `C507`, `C508`, `C509`: LF resonance/RX trim options; leave open until the
  actual external coil has been measured and the receive path checked.

They are marked in `bom-master.csv` and removed from both `bom-jlcpcb.csv` and
`cpl-jlcpcb.csv`. Any additional schematic part carrying a truthy `DNP` field is
handled the same way. The effective list is recorded in `release-check.txt` and
`release-info.json`. The master BOM always contains the columns `Manufacturer`,
`MPN` and `LCSC`; empty fields are not silently invented. For an assembled order,
use `-RequireCompleteProcurement`; the command blocks while any CPL part lacks
one of those three identifiers.

`bom-jlcpcb.csv` contains only designators also present in the generated SMT
position file. Through-hole, mixed-pad and explicitly manual parts are listed in
`bom-manual-or-review.csv`. The file `hardware/assembly-variants.csv` is a design
planning aid, not yet a complete variant definition for every dependent passive.
Do not create a cost-down variant simply by deleting its main IC from the BOM.

JLCPCB rotations are not universal library data. Review **every** pin-1,
polarized, connector, LED, diode, QFN/LGA and module orientation in JLCPCB's 2D
assembly viewer against KiCad before accepting the order. The generated CPL is a
coordinate export, not that visual sign-off.

## Suggested JLCPCB prototype settings

These are ordering targets, not a substitute for matching the final KiCad board
stack-up and design rules:

| Setting | Prototype target |
| --- | --- |
| Base material | FR-4 |
| Layer count | 4 |
| Board thickness | 1.2 mm |
| Finished outline | 85.60 x 53.98 mm, including the specified corner radii |
| Copper weight | JLC04121H-7628 target: 1 oz outer, 0.5 oz inner |
| Surface finish | ENIG recommended for the fine-pitch/QFN/LGA prototype |
| Solder mask | Both sides; color is optional |
| Silkscreen | Both sides if present in the reviewed Gerbers |
| Via treatment | Tented by default; explicitly review RF, thermal and test vias |
| Impedance | Do not select a generic value blindly; use the chosen JLC 4-layer stack-up and recalculate RF traces |
| Assembly side | Two-sided PCBA required by the dense card layout; review both CPL sides and the added setup cost |
| Quantity | Five boards is a sensible first characterization batch |

Select the exact `JLC04121H-7628` structure in the quote, then compare
JLCPCB's live stack-up table with the board file before the
final RF routing. Enter its dielectric heights and copper thicknesses in KiCad,
then recalculate the 50-ohm Sub-GHz feed geometry. The
E07-900MM10S pin-6 antenna path uses a tuneable pi network and the inboard
T3-868M spring; both require measurement with the assembled mechanical stack.
If the final stack-up is
not represented in the board file, the fabrication ZIP must not be released.

Keep the credit-card outline free of factory tooling holes. If panel rails,
fiducials or tooling holes are needed, request them on removable rails and check
USB, optical and antenna edge clearances in the DFM viewer. Do not allow an
automatic outline change without comparing the returned production file.

## Mandatory prototype validation

Passing ERC/DRC only proves consistency against the encoded rules. It does not
prove electrical, RF, thermal or battery safety. Before a larger build:

- Power the first board from a current-limited supply without a LiPo. Validate
  shorts, USB inrush, charger/power-path behavior, 3.3 V stability, 5 V enable/
  disable and load transients. Fit `C109` only from measured evidence.
- Verify LiPo polarity, protection cutoffs, charge current, temperature behavior
  and no back-powering through USB, headers or peripherals before unattended
  charging.
- Characterize the NFC loop on the finished board with suitable RF/VNA or NFC
  measurement equipment. Select `C310`-`C312` and the main matching network from
  measurements, then re-run ERC/DRC and issue a new revision.
- Validate the Sub-GHz antenna/feed/connector with the enclosure and intended
  antenna. Regulatory limits, permitted bands and transmit power depend on the
  country and use case.
- Validate the external LF coil only after measuring its inductance and fitting
  reviewed values for `C506`-`C509`. Check HTRC phase, current, resonant voltage,
  ANTFAIL behavior and read range before extended operation.
- Inspect all fine-pitch and exposed-pad devices, then exercise USB, microSD,
  LF RFID, IR, NFC, sensors and every expansion voltage under load.

Only after those results are recorded should the project lose its
`prototype_only` status. The exporter intentionally writes
`production_approved: false` and `rf_and_nfc_tuning_required: true` into every
release metadata file; a ZIP by itself is never approval to mass-produce.

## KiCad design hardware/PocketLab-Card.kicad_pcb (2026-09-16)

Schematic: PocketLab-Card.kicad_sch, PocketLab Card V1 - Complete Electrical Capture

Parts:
A1: T3-868M SPRING ANTENNA; T3-868M_Edge_Solder; MPN T3-868M; LCSC C381193
AE1: PCB NFC LOOP - TUNE ON V1; NFC_Loop_35x27mm_4T_TUNE
C101: 4.7nF 1kV; C_0805_2012Metric; MPN C0805C472KDRAC7800; LCSC C5565742
C102, C106, C107, C118, C120, C121, C122, C203, C301, C304, C305, C401, C510, C601, C603, C604, C605, C606, C701, C702, C703, C704, C705, C706, C707: 100nF; C_0402_1005Metric; MPN CL05B104KO5NNNC; LCSC C1525
C103, C105: 4.7uF 10V; C_0603_1608Metric; MPN CL10A475KO8NNNC; LCSC C19666
C104: 22uF 10V; C_0805_2012Metric; MPN TCC0805X5R226K100FT; LCSC C380336
C108, C114, C117, C119: 10uF; C_0805_2012Metric; MPN CL21A106KAYNNNE; LCSC C15850
C109: 10uF DNP - populate only after VSYS stability test; C_0805_2012Metric; MPN CL21A106KAYNNNE; LCSC C15850; not fitted
C110, C111, C112, C115, C116: 22uF; C_0805_2012Metric; MPN TCC0805X5R226K100FT; LCSC C380336
C113, C308, C309: 220pF C0G; C_0603_1608Metric; MPN CL10C221JB8NNNC; LCSC C27675
C123, C124: 10uF 25V X5R HF; C_0805_2012Metric; MPN CL21A106KAYNNNE; LCSC C15850
C201: 1uF; C_0402_1005Metric; MPN CL05A105KA5NQNC; LCSC C52923
C202, C511: 10uF; C_0603_1608Metric; MPN CL10A106KP8NNNC; LCSC C19702
C302: 100nF AVDD; C_0402_1005Metric; MPN CL05B104KO5NNNC; LCSC C1525
C303: 4.7uF VBAT bulk; C_0603_1608Metric; MPN CL10A475KO8NNNC; LCSC C19666
C306, C307: 22pF C0G; C_0603_1608Metric; MPN CL10C220JB8NNNC; LCSC C1653
C310, C311, C312: DNP MATCH; C_0603_1608Metric; not fitted
C313: 10uF DVDD bulk; C_0603_1608Metric; MPN CL10A106KP8NNNC; LCSC C19702
C314: 100nF TVDD; C_0402_1005Metric; MPN CL05B104KO5NNNC; LCSC C1525
C315: 4.7uF TVDD bulk; C_0603_1608Metric; MPN CL10A475KO8NNNC; LCSC C19666
C316: 100nF PVDD; C_0402_1005Metric; MPN CL05B104KO5NNNC; LCSC C1525
C317: 100nF VBAT; C_0402_1005Metric; MPN CL05B104KO5NNNC; LCSC C1525
C318: 1nF C0G RX COUPLING; C_0603_1608Metric; MPN CL10C102JB8NNNC; LCSC C163508
C402, C602: 4.7uF; C_0603_1608Metric; MPN CL10A475KO8NNNC; LCSC C19666
C403, C404: DNP SUBGHZ MATCH; C_0603_1608Metric; not fitted
C501: 100nF HTRC supply; C_0402_1005Metric; MPN CL05B104KO5NNNC; LCSC C1525
C502: 10uF HTRC pulse reservoir; C_0805_2012Metric; MPN CL21A106KAYNNNE; LCSC C15850
C503: 100nF CEXT; C_0402_1005Metric; MPN CL05B104KO5NNNC; LCSC C1525
C504: 100nF QGND; C_0402_1005Metric; MPN CL05B104KO5NNNC; LCSC C1525
C505: 100nF C0G COIL ISOLATION; C_1206_3216Metric; MPN 1206CG104J500NT; LCSC C46348
C506: 3.9nF C0G LF RESONANCE; C_0805_2012Metric; MPN CL21C392JBFNNNE; LCSC C307553
C507: 100pF C0G DNP LF TUNE; C_0603_1608Metric; MPN CL10C101JB8NNNC; LCSC C14858; not fitted
C508: 220pF C0G DNP LF TUNE; C_0603_1608Metric; MPN CL10C221JB8NNNC; LCSC C27675; not fitted
C509: 10pF C0G DNP RX EMI; C_0603_1608Metric; MPN CL10C100JB8NNNC; LCSC C1634; not fitted
C512: 47uF 6.3V LOW-ESR; C_1206_3216Metric; MPN CC1206MKX5R5BB476; LCSC C110047
C513: 100nF OSC supply; C_0402_1005Metric; MPN CL05B104KO5NNNC; LCSC C1525
C515: 100nF LV-AT supply; C_0402_1005Metric; MPN CL05B104KO5NNNC; LCSC C1525
C516: 100nF LVC supply; C_0402_1005Metric; MPN CL05B104KO5NNNC; LCSC C1525
C517: 100nF secure element; C_0402_1005Metric; MPN CL05B104KO5NNNC; LCSC C1525
C607, C617: 22uF 10V X5R IR BUFFER; C_1206_3216Metric; MPN TCC1206X5R226K100HT; LCSC C7393980
C608: 100nF IR HF; C_0402_1005Metric; MPN CL05B104KO5NNNC; LCSC C1525
C609: 100nF X7R; C_0402_1005Metric; MPN CL05B104KO5NNNC; LCSC C1525
D1, D2, D3: VSMY14940 940nm side-view; LED_Vishay_VSMY14940_SideView; MPN VSMY14940; LCSC C511069
D101: SMF5.0A; D_SOD-123F; MPN SMF5.0A; LCSC C151296
F1: Littelfuse 1206L075/13.2; Fuse_1206_3216Metric; MPN 1206L075/13.2WR; LCSC C207036
J1: USB-C DATA/POWER; USB_C_Receptacle_HRO_TYPE-C-31-M-12; MPN TYPE-C-31-M-12; LCSC C165948
J2: microSD; microSD_HC_Molex_104031-0811; MPN 104031-0811; LCSC C585350
J3: EXTERNAL 400uH LF COIL; PinHeader_1x02_P2.54mm_Vertical
J4: PROTECTED 1S LiPo 3.7V; JST_PH_S2B-PH-SM4-TB_1x02-1MP_P2.00mm_Horizontal; MPN S2B-PH-SM4-TB(LF)(SN); LCSC C295747
J5: 30-PIN 2.54mm DUPONT GRID; Dupont_Grid_6x5_P2.54mm
L6: 1.5uH 5.2A SMHT4020; ShunXiangNuo_SMHT4020; MPN SMHT4020-1R5MT; LCSC C46469583
L7: 1uH 4.15A SLW4030S; Sunltech_SLW4030S; MPN SLW4030S1R0NST; LCSC C206354
L301, L302: 560nH C0G/Q; L_0805_2012Metric; MPN FHW0805UFR56JST; LCSC C304279
LED1, LED2, LED3, LED4: WS2812B-2020; LED_WS2812B-2020_PLCC4_2.0x2.0mm; MPN WS2812B-2020; LCSC C965555
Q1: AO3400A IR DRIVER; SOT-23; MPN AO3400A; LCSC C20917
Q2: CSD16406Q3 DISCHARGE; CSD16406Q3_VSON-8_3.3x3.3mm_P0.65mm_JLC; MPN CSD16406Q3; LCSC C2861720
Q3: CSD16406Q3 CHARGE; CSD16406Q3_VSON-8_3.3x3.3mm_P0.65mm_JLC; MPN CSD16406Q3; LCSC C2861720
R101, R102: 5.1k 1%; R_0402_1005Metric; MPN 0402WGF5101TCE; LCSC C25905
R103: 1M; R_0402_1005Metric; MPN 0402WGF1004TCE; LCSC C26083
R104: 330R; R_0402_1005Metric; MPN 0402WGF3300TCE; LCSC C25104
R105: 2.2k; R_0805_2012Metric; MPN 0805W8F2201T5E; LCSC C17520
R106, R107: 5.1M; R_0402_1005Metric; MPN 0402WGF5104TCE; LCSC C270595
R108: 10k TS fixed; R_0805_2012Metric; MPN 0805W8F1002T5E; LCSC C17414
R109, R110, R115, R122, R124, R126, R127, R128, R603: 100k; R_0402_1005Metric; MPN 0402WGF1003TCE; LCSC C25741
R111: 3.48k 1%; R_0402_1005Metric; MPN 0402WGF3481TCE; LCSC C22065
R112: 3.01k 1%; R_0402_1005Metric; MPN 0402WGF3011TCE; LCSC C25889
R113: 1.78k 1%; R_0402_1005Metric; MPN 0402WGF1781TCE; LCSC C113478
R114: 68.1k 1%; R_0402_1005Metric; MPN 0402WGF6812TCE; LCSC C11537
R116, R125, R203, R204, R301, R519, R607, R608, R609, R703: 10k; R_0402_1005Metric; MPN 0402WGF1002TCE; LCSC C25744
R117: 470k 1%; R_0402_1005Metric; MPN 0402WGF4703TCE; LCSC C25790
R118: 150k 1%; R_0402_1005Metric; MPN 0402WGF1503TCE; LCSC C25755
R119: 10k; R_0805_2012Metric; MPN 0805W8F1002T5E; LCSC C17414
R120: 732k 1%; R_0402_1005Metric; MPN 0402WGF7323TCE; LCSC C27016
R121: 100k 1%; R_0402_1005Metric; MPN 0402WGF1003TCE; LCSC C25741
R123: 60.4k 1%; R_0402_1005Metric; MPN 0402WGF6042TCE; LCSC C25911
R129: 0R SPI CROSSOVER; R_0805_2012Metric; MPN 0805W8F0000T5E; LCSC C17477
R201, R202: 22R; R_0805_2012Metric; MPN 0805W8F220JT5E; LCSC C17561
R302: 10k RESET default asserted; R_0402_1005Metric; MPN 0402WGF1002TCE; LCSC C25744
R303, R304: 0R MATCH; R_0603_1608Metric; MPN 0603WAF0000T5E; LCSC C21189
R305: 2.7k RX TAP; R_0603_1608Metric; MPN 0603WAF2701T5E; LCSC C13167
R306: 1k VMID BIAS; R_0603_1608Metric; MPN 0603WAF1001T5E; LCSC C21190
R401, R402, R403, R404, R510, R511, R512, R513: 22R; R_0402_1005Metric; MPN 0402WGF220JTCE; LCSC C25092
R405: 0R SUBGHZ MATCH; R_0603_1608Metric; MPN 0603WAF0000T5E; LCSC C21189
R406: 100k CS SAFE-HIGH; R_0402_1005Metric; MPN 0402WGF1003TCE; LCSC C25741
R501: 100R QOD discharge; R_0402_1005Metric; MPN 0402WGF1000TCE; LCSC C25076
R502: 47R 0.5W ANTENNA CURRENT LIMIT; R_1210_3225Metric; MPN 1210W2F470JT5E; LCSC C474213
R503: 1k LF EMI RETURN; R_0402_1005Metric; MPN 0402WGF1001TCE; LCSC C11702
R504: 150k 1% RX DIVIDER; R_0402_1005Metric; MPN 0402WGF1503TCE; LCSC C25755
R506: 100k SAFE-OFF; R_0402_1005Metric; MPN 0402WGF1003TCE; LCSC C25741
R509: 10k PAIR pull-up; R_0402_1005Metric; MPN 0402WGF1002TCE; LCSC C25744
R514, R515, R516, R517, R518: 47k; R_0402_1005Metric; MPN 0402WGF4702TCE; LCSC C25792
R601, R610, R611: 68R 0.25W anti-surge; R_0603_1608Metric; MPN AS03W4J0680T5E; LCSC C966162
R602, R604, R710, R711, R712, R713, R715, R716, R717, R718, R719, R720, R721, R730, R731, R732, R733, R734: 100R; R_0402_1005Metric; MPN 0402WGF1000TCE; LCSC C25076
R605: 68R; R_0402_1005Metric; MPN 0402WGF680JTCE; LCSC C25131
R606: 100R PAIR GPIO PROTECTION; R_0402_1005Metric; MPN 0402WGF1000TCE; LCSC C25076
R701: 3.3k; R_0805_2012Metric; MPN 0805W8F3301T5E; LCSC C26010
R702: 3.3k; R_0402_1005Metric; MPN 0402WGF3301TCE; LCSC C25890
R714: 100R BOARD TEMP PROBE; R_0402_1005Metric; MPN 0402WGF1000TCE; LCSC C25076
R722, R723, R724, R725, R726, R727, R728, R729: 220R EXPANSION PROTECTION; R_0402_1005Metric; MPN 0402WGF2200TCE; LCSC C25091
R735: 100k EN pull-down; R_0805_2012Metric; MPN 0805W8F1003T5E; LCSC C149504
R736: 10k 1% BOARD TEMP BIAS; R_0402_1005Metric; MPN 0402WGF1002TCE; LCSC C25744
RT701: 10k NTC B3950 1%; R_0603_1608Metric; MPN KNTC0603/10KF3950; LCSC C2892547
SJ1: TS FIXED / CUT FOR EXT NTC; SolderJumper-2_P1.3mm_Bridged_RoundedPad1.0x1.5mm
SW1: RESET; SW_HYP_1TS015A_3.0x2.0mm; MPN 1TS015A-1600-0600-CT; LCSC C256104
SW2: BOOT; SW_HYP_1TS015A_3.0x2.0mm; MPN 1TS015A-1600-0600-CT; LCSC C256104
SW3: UP; SW_HYP_1TS015A_3.0x2.0mm; MPN 1TS015A-1600-0600-CT; LCSC C256104
SW4: DOWN; SW_HYP_1TS015A_3.0x2.0mm; MPN 1TS015A-1600-0600-CT; LCSC C256104
SW5: MAIN POWER OFF / ON; SW_SPDT_Shouhan_MSK12C02; MPN MSK12C02; LCSC C431540
SW6: PAIR; SW_HYP_1TS015A_3.0x2.0mm; MPN 1TS015A-1600-0600-CT; LCSC C256104
SW7: SELECT; SW_HYP_1TS015A_3.0x2.0mm; MPN 1TS015A-1600-0600-CT; LCSC C256104
SW8: AUX CONFIG; SW_SPST_CK_KXT3; MPN KXT311LHS
TP101: BATTERY CELL_POS; TestPoint_Pad_D1.0mm
TP102: BATTERY CELL_NEG; TestPoint_Pad_D1.0mm
TP103: BATTERY BAT_FET_MID; TestPoint_Pad_D1.0mm
TP104: BATTERY GND; TestPoint_Pad_D1.0mm
TP105: POWER VBUS_USB; TestPoint_Pad_D1.0mm
TP106: POWER VBUS_FUSED; TestPoint_Pad_D1.0mm
TP107: POWER VSYS; TestPoint_Pad_D1.0mm
TP108: POWER +3V3; TestPoint_Pad_D1.0mm
TP109: POWER +5V_RAW; TestPoint_Pad_D1.0mm
TP110: POWER +5V_AUX; TestPoint_Pad_D1.0mm
TP201: JTAG_STRAP_TP; TestPoint_Pad_D1.0mm
TP202: STRAP_BOOT_TP; TestPoint_Pad_D1.0mm
TP203: STRAP_VDD_SPI_TP; TestPoint_Pad_D1.0mm
TP301: NFC_LOADMOD TEST; TestPoint_Pad_D1.0mm
TP502: LF ANTENNA TAP - HIGH VOLTAGE; TestPoint_Pad_D1.0mm
U1: ESP32-S3-WROOM-1-N8R2; ESP32-S3-WROOM-1_PhysicalCourtyard; MPN ESP32-S3-WROOM-1-N8R2; LCSC C2913204
U2: PN5321A3HN/C106; HVQFN-40-1EP_6x6mm_P0.5mm_EP4.1x4.1mm; MPN PN5321A3HN/C106; LCSC C880904
U3: E07-900MM10S 855-925MHz; E07-900MM10S; MPN E07-900MM10S; LCSC C5844212
U4: HTRC11001T/03EE,11 125kHz; SO-14_3.9x8.65mm_P1.27mm; MPN HTRC11001T/03EE,11; LCSC C501317
U5: BQ24074RGTR; VQFN-16-1EP_3x3mm_P0.5mm_EP1.6x1.6mm_ThermalVias; MPN BQ24074RGTR; LCSC C54313
U6: TPS63070RNMR 3V3; TPS63070_RNM0015A; MPN TPS63070RNMR; LCSC C109322
U7: TPS61023DRLR 5V BOOST; SOT-563; MPN TPS61023DRLR; LCSC C919459
U8: MAX17048G+T10; TDFN-8-1EP_2x2mm_P0.5mm_EP0.8x1.2mm; MPN MAX17048G+T10; LCSC C2682616
U9: TCA9535PWR; TSSOP-24_4.4x7.8mm_P0.65mm; MPN TCA9535PWR; LCSC C130204
U10: BMI270 (FULL OPTION); Bosch_LGA-14_3x2.5mm_P0.5mm; MPN BMI270; LCSC C2836813
U11: BMP390 (FULL OPTION); BMP390_LGA-10_2x2mm; MPN BMP390; LCSC C5124834
U12: PCF8563T; SOIC-8_3.9x4.9mm_P1.27mm; MPN PCF8563T/5,518; LCSC C7440
U13: TSOP75338WTR 38kHz; TSOP75338WTR_HeimdallW_SideView; MPN TSOP75338WTR; LCSC C7365598
U14: BQ29700DSE; WSON-6_1.5x1.5mm_P0.5mm; MPN BQ29700DSER; LCSC C183096
U15: TPS2553DBVR 500mA LIMIT; SOT-23-6; MPN TPS2553DBVR; LCSC C55266
U16: USBLC6-4SC6Y; SOT-23-6; MPN USBLC6-4SC6Y; LCSC C435848
U17: TPS22919DCKR LF 5V LOAD SWITCH; SOT-363_SC-70-6; MPN TPS22919DCKR; LCSC C2149796
U18: TCA9534PWR INTERNAL CONTROL; TSSOP-16_4.4x5mm_P0.65mm; MPN TCA9534PWR; LCSC C783615
U19: SRV05-4MR6T1G SD ESD; SOT-23-6; MPN SRV05-4MR6T1G; LCSC C604719
U20: SN74AHCT1G126DBVR RGB LEVEL SHIFT; SOT-23-5; MPN SN74AHCT1G126DBVR; LCSC C163712
U21: SN74LV125ATPWR LF/SPI 3V3-TO-5V IOFF; TSSOP-14_4.4x5mm_P0.65mm; MPN SN74LV125ATPWR; LCSC C2675655
U22: SN74LVC1G126DBVR LF 5V-TO-3V3 TRI-STATE; SOT-23-5; MPN SN74LVC1G126DBVR; LCSC C7834
U23: ATECC608C-SSHDA-T; SOIC-8_3.9x4.9mm_P1.27mm; MPN ATECC608C-SSHDA-T; LCSC C28975195
U24: SRV05-4MR6T1G J5 BUS ESD; SOT-23-6; MPN SRV05-4MR6T1G; LCSC C604719
U25: SRV05-4MR6T1G J5 SPI ESD; SOT-23-6; MPN SRV05-4MR6T1G; LCSC C604719
Y301: 27.12MHz crystal (pins 2/4 shield); Crystal_SMD_3225-4Pin_3.2x2.5mm; MPN XXDBBCNANF-27.12M; LCSC C124317
Y501: 4MHz 5V CMOS OSCILLATOR; Oscillator_SMD_EuroQuartz_XO32-4Pin_3.2x2.5mm_RotB; MPN OH2EL89CFI-111YLC-4M; LCSC C42448900
Y701: 32.768kHz CL=7pF; Crystal_SMD_3215-2Pin_3.2x1.5mm; MPN ABS07-32.768KHZ-7-T; LCSC C276424

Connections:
/+3V3: C110.1, C111.1, C112.1, C124.1, C202.1, C203.1, C303.1, C316.1, C317.1, C401.1, C402.1, C510.1, C511.1, C512.1, C516.1, C517.1, C701.1, C702.1, C703.1, C704.1, C705.1, C706.1, C707.1, J2.4 (VDD), J5.1, R109.2, R110.2, R117.1, R119.2, R124.2, R125.2, R203.2, R204.2, R406.2, R509.2, R514.2, R515.2, R516.2, R517.2, R518.2, R519.2, R604.1, R607.2, R608.2, R609.2, R701.2, R702.2, R703.2, R736.1, TP108.1, U1.2 (3V3), U2.23 (PVDD), U2.40 (VBAT), U3.1, U6.7, U6.8, U9.24 (VCC), U10.5, U10.8, U10.12, U11.1, U11.6, U11.10, U12.8 (VDD), U18.1 (A0), U18.16 (VDD), U19.5 (VP), U22.5 (VCC), U23.8 (VCC), U24.5 (VP), U25.5 (VP); also elsewhere on the board
/+5V_AUX: C118.1, C119.1, J5.29, TP110.1, U15.6
/+5V_RAW: C113.1, C115.1, C116.1, C117.1, C603.1, C604.1, C605.1, C606.1, C607.1, C608.1, C609.1, C617.1, LED1.1 (VDD), LED2.1 (VDD), LED3.1 (VDD), LED4.1 (VDD), R120.1, R601.1, R610.1, R611.1, TP109.1, U7.6, U15.1, U17.1, U20.5 (VCC)
/AUX5_EN: R127.1, U15.3, U18.6 (P2)
/AUX5_FAULT_N: R124.1, U9.7 (P03), U15.4
/BAT_COUT: Q3.4, R107.1, U14.2 (Cout)
/BAT_DOUT: Q2.4, R106.1, U14.3 (Dout)
/BAT_FET_MID: Q2.5, Q3.5, TP103.1
/BAT_SENSE: C102.1, R104.2, U14.5 (BAT)
/BAT_VMINUS: R105.1, U14.6 (V-)
/BMI_INT1: U9.9 (P05), U10.4
/BMI_INT2: U9.10 (P06), U10.9
/BOARD_TEMP_ADC: R714.1, R736.2, RT701.1, U1.17 (IO9)
/BOARD_TEMP_HDR: J5.7, R714.2
/BOOST5_EN: R122.1, U7.2, U18.10 (P5), U20.1
/BOOT_N: R204.1, SW2.1, U1.27 (IO0)
/BQ_EN1: R115.1, U5.6 (EN1), U18.4 (P0)
/BQ_EN2: R128.1, U5.5 (EN2)
/CELL_NEG: C102.2, J4.2, Q2.1, Q2.2, Q2.3, R106.2, TP102.1, U14.4 (VSS)
/CELL_POS: C104.1, C120.1, C121.1, J4.1, R104.1, TP101.1, U5.2 (BAT), U5.3 (BAT), U8.3
/CHARGER_CHG_N: R110.1, U5.9 (~CHG), U9.5 (P01)
/CHARGER_PGOOD_N: R109.1, U5.7 (~PGOOD), U9.6 (P02)
/CHG_DISABLE: R126.1, U5.4 (~CE), U18.5 (P1)
/CHG_ILIM: R111.1, U5.12 (ILIM)
/CHG_ISET: R113.1, U5.16 (ISET)
/CHG_ITERM: R112.1, U5.15 (ITERM)
/CHG_TMR: R114.1, U5.14 (TMR)
/CHG_TS: J5.28, SJ1.1 (A), U5.1 (TS)
/CHG_TS_FIXED: R108.1, SJ1.2 (B)
/ESP_EN: C201.1, R203.1, SW1.1, U1.3 (EN); also elsewhere on the board
/EX0: J5.15, R722.2
/EX0_INT: R722.1, U9.13 (P10)
/EX1: J5.16, R723.2
/EX1_INT: R723.1, U9.14 (P11)
/EX2: J5.17, R724.2
/EX2_INT: R724.1, U9.15 (P12)
/EX3: J5.18, R725.2
/EX3_INT: R725.1, U9.16 (P13)
/EX4: J5.19, R726.2
/EX4_INT: R726.1, U9.17 (P14)
/EX5: J5.20, R727.2
/EX5_INT: R727.1, U9.18 (P15)
/EX6: J5.21, R728.2
/EX6_INT: R728.1, U9.19 (P16)
/EX7: J5.22, R729.2
/EX7_INT: R729.1, U9.20 (P17)
/FG_ALERT_N: R125.1, U8.5, U9.8 (P04)
/GND: C101.2, C103.2, C104.2, C105.2, C106.2, C107.2, C108.2, C109.2, C110.2, C111.2, C112.2, C114.2, C115.2, C116.2, C117.2, C118.2, C119.2, C120.2, C121.2, C122.2, C123.2, C124.2, C201.2, C202.2, C203.2, C301.2, C302.2, C303.2, C304.2, C305.2, C306.2, C307.2, C308.2, C309.2, C311.2, C312.2, C313.2, C314.2, C315.2, C316.2, C317.2, C401.2, C402.2, C403.2, C404.2, C501.2, C502.2, C503.2, C504.2, C510.2, C511.2, C512.2, C513.2, C515.2, C516.2, C517.2, C601.2, C602.2, C603.2, C604.2, C605.2, C606.2, C607.2, C608.2, C609.2, C617.2, C701.2, C702.2, C703.2, C704.2, C705.2, C706.2, C707.2, D101.2 (A), J1.A1 (GND), J1.A12 (GND), J1.B1 (GND), J1.B12 (GND), J2.6 (VSS), J2.9 (DET_B), J2.SH (SHIELD), J5.2, J5.30, LED1.3 (VSS), LED2.3 (VSS), LED3.3 (VSS), LED4.3 (VSS), Q1.2 (S), Q3.1, Q3.2, Q3.3, R101.2, R102.2, R103.2, R105.2, R107.2, R108.2, R111.2, R112.2, R113.2, R114.2, R115.2, R118.2, R121.2, R122.2, R123.2, R126.2, R127.2, R128.2, R302.2, R503.2, R506.2, R603.2, R735.2, RT701.2, SW1.2, SW2.2, SW3.2, SW4.2, SW5.1 (A), SW6.2, SW7.2, SW8.2, TP104.1, U1.1 (GND), U1.40 (GND), U1.41 (GND), U2.1 (DVSS), U2.3 (TVSS1), U2.7 (TVSS2), U2.11 (AVSS), U2.17 (I1), U2.18 (TESTEN), U2.41 (AVSS), U3.2, U3.7, U3.16, U4.1 (VSS), U4.5 (MODE), U5.8 (VSS), U5.17 (VSS), U6.4, U6.10, U6.15, U7.4, U8.1, U8.4, U8.6, U8.9, U9.2 (A1), U9.3 (A2), U9.12 (GND), U9.21 (A0), U10.1, U10.6, U10.7, U11.3, U11.5, U11.8, U11.9, U12.4 (VSS), U13.1, U13.4, U15.2, U16.2 (GND), U17.2, U18.2 (A1), U18.3 (A2), U18.8 (GND), U19.2 (VN), U20.3 (GND), U21.1, U21.2, U21.4, U21.7, U21.9, U21.10, U21.13, U22.3 (GND), U23.4 (GND), U24.2 (VN), U25.2 (VN), Y301.2, Y301.4, Y501.2; also elsewhere on the board
/GPIO1: J5.3, R710.2
/GPIO1_MCU: R710.1, U1.39 (IO1)
/GPIO2: J5.4, R711.2
/GPIO2_MCU: R711.1, U1.38 (IO2)
/GPIO4: J5.5, R712.2
/GPIO4_MCU: R712.1, U1.4 (IO4)
/GPIO8: J5.6, R713.2
/GPIO8_MCU: R713.1, U1.12 (IO8)
/GPIO38_MCU: R606.1, U1.31 (IO38)
/GPIO40: J5.8, R715.2
/GPIO40_MCU: R715.1, U1.33 (IO40)
/GPIO41: J5.9, R716.2
/GPIO41_MCU: R716.1, U1.34 (IO41)
/GPIO42: J5.10, R717.2
/GPIO42_MCU: R717.1, U1.35 (IO42)
/GPIO43: J5.11, R718.2
/GPIO43_MCU: R718.1, U1.37 (TXD0)
/GPIO44: J5.12, R719.2
/GPIO44_MCU: R719.1, U1.36 (RXD0)
/GPIO47: J5.13, R720.2
/GPIO47_MCU: R720.1, U1.24 (IO47)
/GPIO48: J5.14, R721.2
/GPIO48_MCU: R721.1, U1.25 (IO48)
/I2C_SCL: R702.1, R731.1, U1.6 (IO6), U2.27 (NSS/P50_SCL/HSU_RX), U8.7, U9.22 (SCL), U10.13, U11.2, U12.6 (SCL), U18.14 (SCL), U23.6 (SCL); also elsewhere on the board
/I2C_SCL_HDR: J5.24, R731.2, U24.3 (IO2)
/I2C_SDA: R701.1, R730.1, U1.5 (IO5), U2.28 (MOSI/SDA/HSU_TX), U8.8, U9.23 (SDA), U10.14, U11.4, U12.5 (SDA), U18.15 (SDA), U23.5 (SDA); also elsewhere on the board
/I2C_SDA_HDR: J5.23, R730.2, U24.1 (IO1)
/IOEXP_INT_N: R703.1, U1.32 (IO39), U9.1 (~INT), U18.13 (~INT)
/IR_GATE: Q1.1 (G), R602.2, R603.1
/IR_LED_A1: D1.2 (A), R601.2
/IR_LED_A2: D2.2 (A), R610.2
/IR_LED_A3: D3.2 (A), R611.2
/IR_LED_K: D1.1 (K), D2.1 (K), D3.1 (K), Q1.3 (D)
/IR_RX: U1.30 (IO37), U13.3
/IR_RX_VS: C601.1, C602.1, R604.2, U13.2
/IR_TX: R602.1, U1.29 (IO36)
/JTAG_STRAP_TP: TP201.1, U1.15 (IO3)
/LF_5V: C501.1, C502.1, C513.1, C515.1, R501.2, U4.3 (VDD), U17.6, U21.14, Y501.1, Y501.4
/LF_ANT_A: C505.2, J3.1, R503.1
/LF_ANT_B: J3.2, R502.1
/LF_CEXT: C503.1, U4.12 (CEXT)
/LF_CLK_4M: U4.6 (XTAL1), Y501.3
/LF_DIN_5V: U4.9 (DIN), U21.11
/LF_DOUT_5V: U4.10 (DOUT), U22.2
/LF_QGND: C504.1, C509.2, U4.13 (QGND)
/LF_QOD: R501.1, U17.5
/LF_RFID_EN: R506.1, U17.3, U18.9 (P4), U22.1
/LF_RX: C509.1, R504.2, U4.14 (RX)
/LF_SCLK_5V: U4.8 (SCLK), U21.6
/LF_TAP: C506.1, C507.1, C508.1, R502.2, R504.1, TP502.1
/LF_TX1: C505.1, U4.4 (TX1)
/LF_TX2: C506.2, C507.2, C508.2, U4.2 (TX2)
/NFC_DVDD: C302.1, C304.1, C313.1, C314.1, C315.1, R301.2, U2.5 (TVDD), U2.8 (AVDD), U2.39 (DVDD)
/NFC_I0: R301.1, U2.16 (I0)
/NFC_IRQ_N: U1.7 (IO7), U2.25 (P70_IRQ)
/NFC_LOADMOD: TP301.1, U2.2 (LOADMOD)
/NFC_LOOP_A: AE1.1, C310.1, C311.1, R303.2, R305.1
/NFC_LOOP_B: AE1.2, C310.2, C312.1, R304.2
/NFC_OSCIN: C306.1, U2.14 (OSCIN), Y301.1
/NFC_OSCOUT: C307.1, U2.15 (OSCOUT), Y301.3
/NFC_RESET_N: R302.1, U2.38 (~RSTPD), U18.7 (P3)
/NFC_RX: C318.2, R306.2, U2.10 (RX)
/NFC_RX_AC: C318.1, R305.2
/NFC_SVDD: C305.1, U2.37 (SVDD)
/NFC_TX1: L301.1, U2.4 (TX1)
/NFC_TX1_F: C308.1, L301.2, R303.1
/NFC_TX2: L302.1, U2.6 (TX2)
/NFC_TX2_F: C309.1, L302.2, R304.1
/NFC_VMID: C301.1, R306.1, U2.9 (VMID)
/PAIR_N: R509.1, R606.2, SW6.1
/PWR_3V3_PG: R119.1, U6.2
/PWR_SW_ON: R116.2, SW5.3 (C)
/RGB_BUF_5V: R605.1, U20.4
/RGB_D1_2: LED1.2 (DOUT), LED2.4 (DIN)
/RGB_D2_3: LED2.2 (DOUT), LED3.4 (DIN)
/RGB_D3_4: LED3.2 (DOUT), LED4.4 (DIN)
/RGB_DATA: U1.18 (IO10), U20.2
/RGB_DIN1: LED1.4 (DIN), R605.2
/RTC_OSCI: U12.1 (OSCI), Y701.1
/RTC_OSCO: U12.2 (OSCO), Y701.2
/SD_CS_DEV: J2.2 (DAT3/CD), R510.2, R515.1, U19.1 (IO1)
/SD_CS_N: R510.1, U1.10 (IO17)
/SD_DAT1: J2.8 (DAT1), R518.1
/SD_DAT2: J2.1 (DAT2), R514.1
/SD_DETECT_N: J2.10 (DET_A), R519.1, U9.4 (P00)
/SD_MISO: J2.7 (DAT0), R513.2, R517.1, U19.6 (IO4)
/SD_MOSI: J2.3 (CMD), R511.2, R516.1, U19.3 (IO2)
/SD_SCK: J2.5 (CLK), R512.2, U19.4 (IO3)
/SPI_MISO: R403.1, R513.1, R734.1, U1.21 (IO13), U22.4
/SPI_MISO_HDR: J5.27, R734.2, U25.1 (IO1)
/SPI_MOSI: R129.2, R511.1, R733.1, U1.19 (IO11), U21.12
/SPI_MOSI_HDR: J5.26, R733.2, U25.3 (IO2)
/SPI_MOSI_JMP: R129.1, R402.1
/SPI_SCK: R401.1, R512.1, R732.1, U1.20 (IO12), U21.5
/SPI_SCK_HDR: J5.25, R732.2, U25.4 (IO3)
/STRAP_BOOT_TP: TP202.1, U1.16 (IO46)
/STRAP_VDD_SPI_TP: TP203.1, U1.26 (IO45)
/SUBGHZ_CS_N: R404.1, U1.22 (IO14)
/SUBGHZ_GDO0: U1.8 (IO15), U3.18
/SUBGHZ_GDO2: U1.9 (IO16), U3.20
/SUBGHZ_RF_ANT: A1.1, C404.1, R405.2
/SUBGHZ_RF_MOD: C403.1, R405.1, U3.6
/SUB_CS_N: R404.2, R406.1, U3.14
/SUB_MISO: R403.2, U3.12
/SUB_MOSI: R402.2, U3.13
/SUB_SCK: R401.2, U3.15
/U6_FB: R117.2, R118.1, U6.5
/U6_L1: L6.1, U6.11
/U6_L2: L6.2, U6.9
/U6_PS_SYNC: R735.1, SW5.2 (B), U6.1, U6.14
/U6_VAUX: C107.1, U6.3
/U7_FB: C113.2, R120.2, R121.1, U7.1
/U7_SW: L7.2, U7.5
/U15_ILIM: R123.1, U15.5
/USB_CC1: J1.A5 (CC1), R101.1, U16.4 (I/O3)
/USB_CC2: J1.B5 (CC2), R102.1, U16.6 (I/O4)
/USB_CONN_N: J1.A7 (D-), J1.B7 (D-), R201.1, U16.3 (I/O2)
/USB_CONN_P: J1.A6 (D+), J1.B6 (D+), R202.1, U16.1 (I/O1)
/USB_D_N: R201.2, U1.13 (USB_D-)
/USB_D_P: R202.2, U1.14 (USB_D+)
/USB_SHIELD: C101.1, J1.SH (SHIELD), R103.1
/USER_BUTTON_A_N: R608.1, SW3.1, U18.11 (P6)
/USER_BUTTON_B_N: R609.1, SW4.1, U18.12 (P7)
/USER_BUTTON_SELECT_N: R607.1, SW7.1, U9.11 (P07)
/VBUS_FUSED: C103.1, C106.1, D101.1 (K), F1.2, TP106.1, U5.13 (IN), U16.5 (VBUS)
/VBUS_USB: F1.1, J1.A4 (VBUS), J1.A9 (VBUS), J1.B4 (VBUS), J1.B9 (VBUS), TP105.1
/VSYS: C105.1, C108.1, C109.1, C114.1, C122.1, C123.1, L7.1, R116.1, TP107.1, U5.10 (OUT), U5.11 (OUT), U6.12, U6.13, U7.3
unnamed: SW8.1, U1.23 (IO21)

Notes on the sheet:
01 USB / BATTERY / POWER
02 ESP32-S3 MCU / USB
03 PN532 NFC / TUNABLE LOOP
04 E07 CC1101 SUB-GHZ
05 LF RFID / SECURITY / MICROSD
06 IR / RGB / BUTTONS
07 SENSORS / RTC / IO EXPANSION

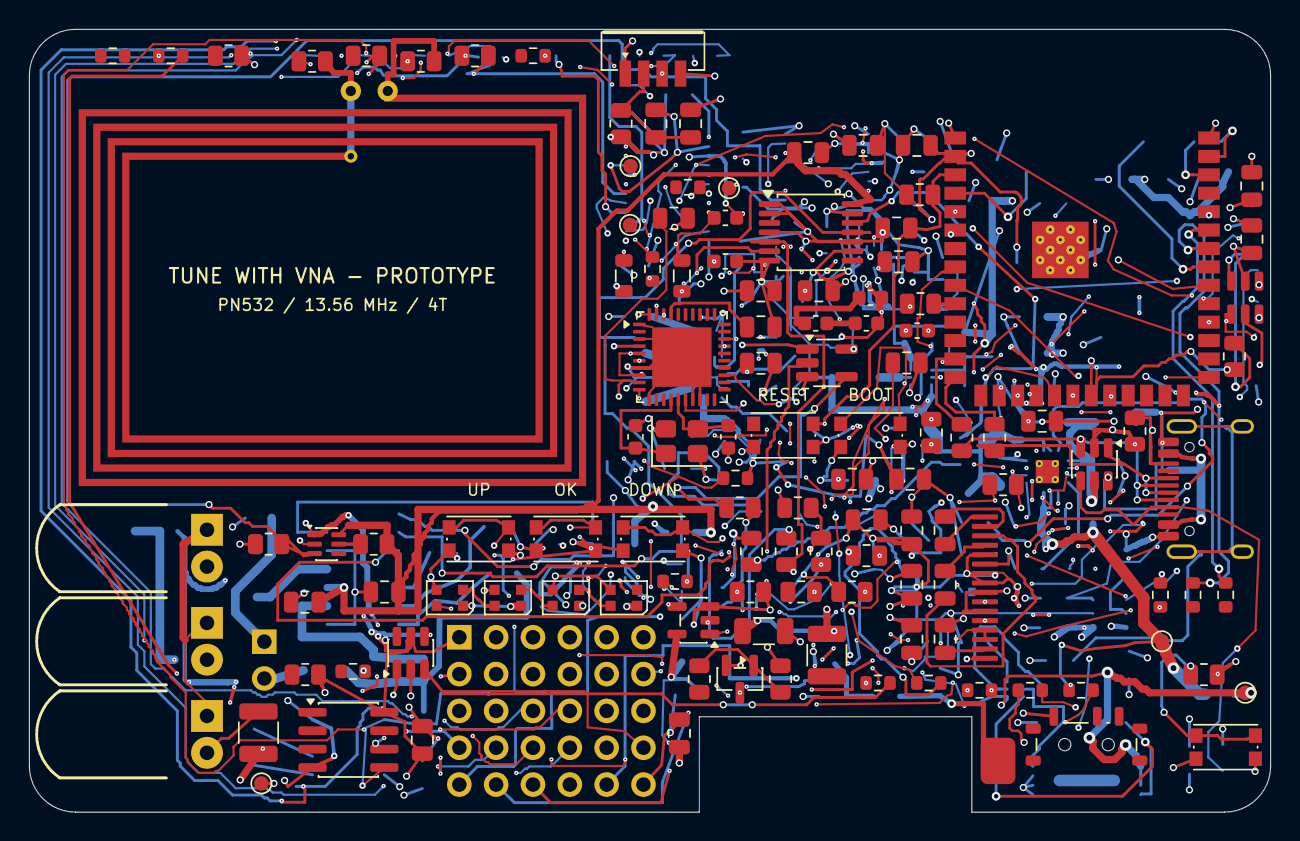
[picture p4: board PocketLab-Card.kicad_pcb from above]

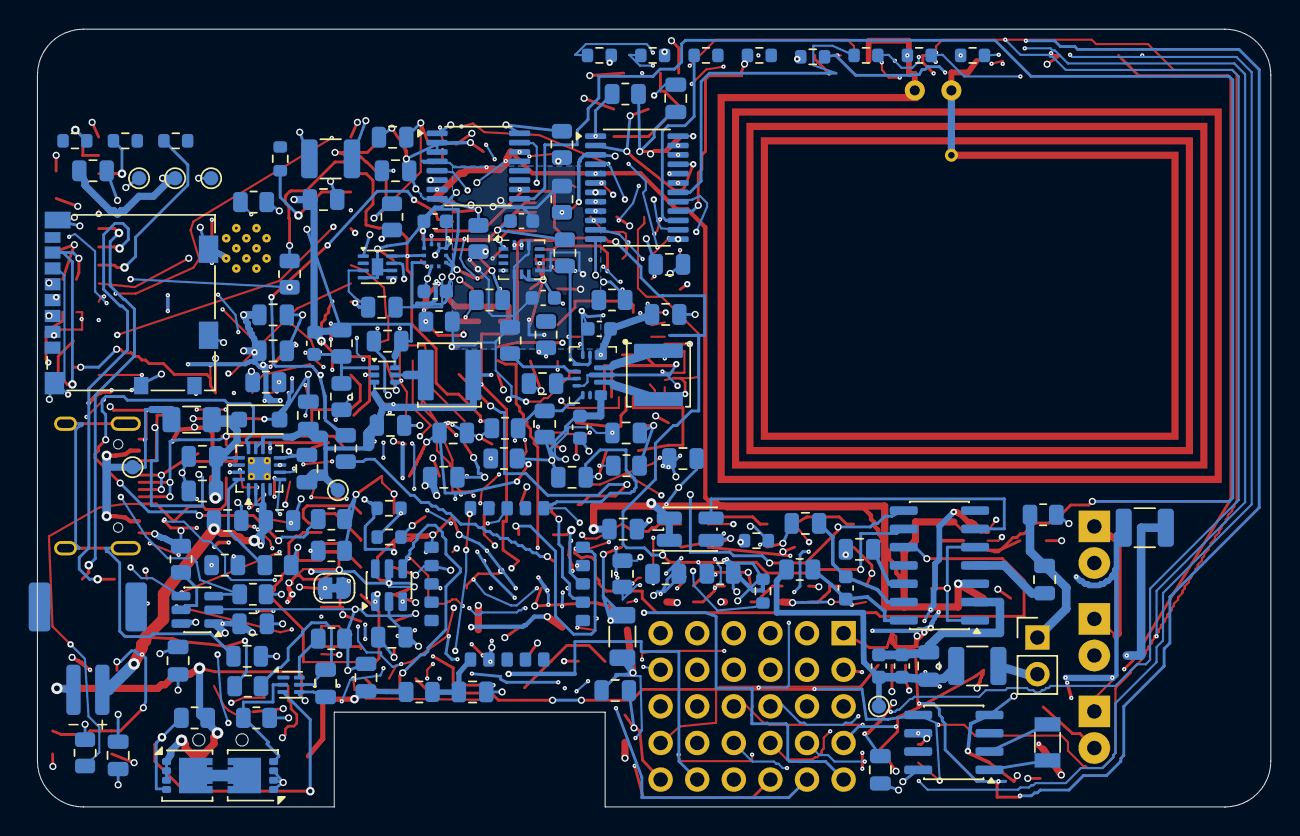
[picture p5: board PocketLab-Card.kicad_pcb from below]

Board: 4 copper layers, 85.6 x 54.0 mm, 264 parts (139 on the bottom side), 180 nets.

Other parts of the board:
C610, C611: 1uF X7R; C_0805_2012Metric
C612, C616: 100nF X7R; C_0805_2012Metric
C613, C615: 4.7uF X5R; C_0805_2012Metric
C614: 2.2uF X7R; C_0805_2012Metric
J8: ER-OLED0.42-1W 72x40 SSD1306B; EastRising_ER-OLED0.42-1W_SolderFPC

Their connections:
/+3V3: C612.1, C613.1, J8.5, J8.7, J8.8; also elsewhere on the board
/ESP_EN: J8.10; also elsewhere on the board
/GND: C612.2, C613.2, C614.2, C615.2, C616.2, J8.6, J8.9, J8.11; also elsewhere on the board
/I2C_SCL: J8.12; also elsewhere on the board
/I2C_SDA: J8.13, J8.14; also elsewhere on the board
/OLED_C1N: C611.2, J8.4
/OLED_C1P: C611.1, J8.3
/OLED_C2N: C610.2, J8.2
/OLED_C2P: C610.1, J8.1
/OLED_VCC: C615.1, C616.1, J8.16
/OLED_VCOMH: C614.1, J8.15

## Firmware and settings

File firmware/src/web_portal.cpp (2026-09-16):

#include "web_portal.h"

#include <WiFi.h>
#include <esp_system.h>

#include "board_pins.h"
#include "firmware_config.h"
#include "json_util.h"
#include "web_ui.h"

namespace pocketlab {

WebPortal::WebPortal(HardwareManager &hardware, StorageManager &storage)
    : hardware_(hardware),
      storage_(storage),
      server_(config::HTTP_PORT),
      webSocket_(config::WEBSOCKET_PORT) {}

bool WebPortal::begin() {
  const uint64_t chipId = ESP.getEfuseMac();
  const uint32_t suffix = static_cast<uint32_t>(chipId & 0x00FFFFFFULL);
  const uint32_t passwordSeed = static_cast<uint32_t>((chipId >> 16) ^ chipId ^ 0xA73C91E5UL);
  char ssidBuffer[24];
  char passwordBuffer[16];
  snprintf(ssidBuffer, sizeof(ssidBuffer), "BomberCard-%06lX",
           static_cast<unsigned long>(suffix));
  snprintf(passwordBuffer, sizeof(passwordBuffer), "PL-%08lX",
           static_cast<unsigned long>(passwordSeed));
  ssid_ = ssidBuffer;
  password_ = passwordBuffer;

  char tokenBuffer[33];
  snprintf(tokenBuffer, sizeof(tokenBuffer), "%08lX%08lX%08lX%08lX",
           static_cast<unsigned long>(esp_random()),
           static_cast<unsigned long>(esp_random()),
           static_cast<unsigned long>(esp_random()),
           static_cast<unsigned long>(esp_random()));
  sessionToken_ = tokenBuffer;

  WiFi.mode(WIFI_AP);
  WiFi.softAPsetHostname(config::HOSTNAME);
  if (!WiFi.softAP(ssid_.c_str(), password_.c_str(), config::WIFI_CHANNEL, false,
                   config::WIFI_MAX_CLIENTS)) {
    return false;
  }

  configureRoutes();
  const char *trackedHeaders[] = {"X-BomberCard-Token"};
  server_.collectHeaders(trackedHeaders, 1);
  server_.begin();

  webSocket_.begin();
  webSocket_.enableHeartbeat(15000, 3000, 2);
  webSocket_.onEvent([this](uint8_t client, WStype_t type, uint8_t *payload,
                            size_t length) {
    if (type == WStype_CONNECTED) {
      String status = buildStatusJson();
      webSocket_.sendTXT(client, status);
    } else if (type == WStype_TEXT) {
      (void)payload;
      (void)length;
      String error = F("{\"type\":\"error\",\"error\":\"websocket_read_only\"}");
      webSocket_.sendTXT(client, error);
    }
  });
  return true;
}

void WebPortal::configureRoutes() {
  server_.on(F("/"), HTTP_GET, [this]() {
    server_.sendHeader(F("Cache-Control"), F("no-store"));
    server_.send_P(200, "text/html; charset=utf-8", WEB_UI);
  });
  server_.on(F("/healthz"), HTTP_GET,
             [this]() { sendJson(200, F("{\"ok\":true}")); });
  server_.on(F("/api/config"), HTTP_GET,
             [this]() { sendJson(200, buildConfigJson()); });
  server_.on(F("/api/status"), HTTP_GET,
             [this]() { sendJson(200, buildStatusJson()); });
  server_.on(F("/api/hardware"), HTTP_GET,
             [this]() { sendJson(200, hardware_.statusJson()); });
  server_.on(F("/api/gpio"), HTTP_GET,
             [this]() { sendJson(200, gpioStatusJson()); });
  server_.on(F("/api/files"), HTTP_GET, [this]() { handleFileList(); });
  server_.on(F("/api/file"), HTTP_GET, [this]() { handleFileDownload(); });
  server_.on(F("/api/file"), HTTP_DELETE, [this]() { handleFileDelete(); });
  server_.on(F("/api/upload"), HTTP_POST,
             [this]() { handleUploadComplete(); },
             [this]() { handleUploadChunk(); });
  server_.on(F("/api/lf/power"), HTTP_POST, [this]() { handleLfPower(); });
  server_.on(F("/api/lf/diagnose"), HTTP_POST, [this]() { handleLfDiagnose(); });
  server_.on(F("/api/security/pairing-window"), HTTP_POST,
             [this]() { handlePairingArm(); });
  server_.on(F("/api/sd/remount"), HTTP_POST, [this]() { handleSdRemount(); });
  server_.on(F("/api/subghz/tx"), HTTP_POST,
             [this]() { handleLockedTransmit(F("subghz_tx")); });
  server_.on(F("/api/ir/tx"), HTTP_POST,
             [this]() { handleIrTransmit(); });
  server_.on(F("/api/gpio/output"), HTTP_POST,
             [this]() { handleLockedTransmit(F("gpio_output")); });
  server_.onNotFound([this]() { sendError(404, F("not_found")); });
}

void WebPortal::poll() {
  server_.handleClient();
  webSocket_.loop();

  const uint32_t now = millis();
  if (now - lastBroadcastMs_ >= 1000) {
    lastBroadcastMs_ = now;
    String status = buildStatusJson();
    webSocket_.broadcastTXT(status);
  }
}

void WebPortal::sendJson(int code, const String &payload) {
  server_.sendHeader(F("Cache-Control"), F("no-store"));
  server_.send(code, F("application/json; charset=utf-8"), payload);
}

void WebPortal::sendError(int code, const __FlashStringHelper *error) {
  String payload = F("{\"ok\":false,\"error\":\"");
  payload += error;
  payload += F("\"}");
  sendJson(code, payload);
}

bool WebPortal::authorizeMutation() {
  if (server_.hasHeader(F("X-BomberCard-Token")) &&
      server_.header(F("X-BomberCard-Token")) == sessionToken_) {
    return true;
  }
  sendError(403, F("invalid_session_token"));
  return false;
}

String WebPortal::buildStatusJson() const {
  String result;
  result.reserve(1400);
  result += F("{\"type\":\"status\",\"firmware\":{\"name\":\"");
  result += config::FIRMWARE_NAME;
  result += F("\",\"version\":\"");
  result += config::FIRMWARE_VERSION;
  result += F("\",\"hardwareRevision\":");
  result += POCKETLAB_CARD_HW_REV;
  result += F("},\"uptimeMs\":");
  result += millis();
  result += F(",\"freeHeap\":");
  result += ESP.getFreeHeap();
  result += F(",\"wifi\":{\"ssid\":\"");
  result += json::escape(ssid_);
  result += F("\",\"ip\":\"");
  result += WiFi.softAPIP().toString();
  result += F("\",\"clients\":");
  result += WiFi.softAPgetStationNum();
  result += F("},\"hardware\":");
  result += hardware_.statusJson();
  result += F(",\"storage\":");
  result += storage_.statusJson();
  result += '}';
  return result;
}

String WebPortal::buildConfigJson() const {
  String result;
  result.reserve(320);
  result += F("{\"token\":\"");
  result += sessionToken_;
  result += F("\",\"websocketPort\":");
  result += config::WEBSOCKET_PORT;
  result += F(",\"ssid\":\"");
  result += json::escape(ssid_);
  result += F("\",\"txPolicy\":{\"subGhz\":");
  result += json::boolean(config::SUBGHZ_TX_COMPILED);
  result += F(",\"ir\":");
  result += json::boolean(config::IR_TX_COMPILED);
  result += F(",\"gpioOutput\":");
  result += json::boolean(config::GPIO_OUTPUT_COMPILED);
  result += F("}}");
  return result;
}
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

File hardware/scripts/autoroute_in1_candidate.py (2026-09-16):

"""Route selected DRC-reported ordinary-signal opens on In2.Cu.

The dedicated In1.Cu ground plane remains untouched.  Bottom-side endpoints
use adjacent B.Cu->In2.Cu microvias.  Top-side endpoints fan out to an ordinary
through via, which also reaches In2.Cu.  The protected +5V_RAW and +5V_AUX
polygons are treated as hard routing keepouts and all other PWR-layer zones are
refilled around accepted signal copper before saving the candidate.
"""

from __future__ import annotations

import argparse
import heapq
import json
import math
import re
from collections import defaultdict
from dataclasses import dataclass
from pathlib import Path

import pcbnew


TRACK_WIDTH = 0.15
CLEARANCE = 0.25
GRID_STEP = 0.20


def mm(value: int) -> float:
    return pcbnew.ToMM(value)


def iu(value: float) -> int:
    return pcbnew.FromMM(value)


def point(value: tuple[float, float]) -> pcbnew.VECTOR2I:
    return pcbnew.VECTOR2I_MM(*value)


def parse_xy(value: str) -> tuple[float, float]:
    try:
        x, y = value.split(",", 1)
        return float(x), float(y)
    except ValueError as exc:
        raise argparse.ArgumentTypeError("expected X,Y in millimetres") from exc


def distance_to_segment(
    p: tuple[float, float],
    a: tuple[float, float],
    b: tuple[float, float],
) -> float:
    vx, vy = b[0] - a[0], b[1] - a[1]
    wx, wy = p[0] - a[0], p[1] - a[1]
    length_sq = vx * vx + vy * vy
    if length_sq == 0:
        return math.hypot(wx, wy)
    t = max(0.0, min(1.0, (wx * vx + wy * vy) / length_sq))
    return math.hypot(p[0] - (a[0] + t * vx), p[1] - (a[1] + t * vy))


def segments_intersect(
    a: tuple[float, float],
    b: tuple[float, float],
    c: tuple[float, float],
    d: tuple[float, float],
) -> bool:
    def orientation(p, q, r):
        return (q[0] - p[0]) * (r[1] - p[1]) - (q[1] - p[1]) * (r[0] - p[0])

    o1, o2 = orientation(a, b, c), orientation(a, b, d)
    o3, o4 = orientation(c, d, a), orientation(c, d, b)
    return (o1 == 0 or o2 == 0 or o1 * o2 < 0) and (
        o3 == 0 or o4 == 0 or o3 * o4 < 0
    )


def segment_distance(
    a: tuple[float, float],
    b: tuple[float, float],
    c: tuple[float, float],
    d: tuple[float, float],
) -> float:
    if a == b:
        return distance_to_segment(a, c, d)
    if c == d:
        return distance_to_segment(c, a, b)
    if segments_intersect(a, b, c, d):
        return 0.0
    return min(
        distance_to_segment(a, c, d),
        distance_to_segment(b, c, d),
        distance_to_segment(c, a, b),
        distance_to_segment(d, a, b),
    )


@dataclass(frozen=True)
class Endpoint:
    net: str
    pos: tuple[float, float]
    layer: str
    description: str


@dataclass(frozen=True)
class Edge:
    net: str
    start: Endpoint
    end: Endpoint

    @property
    def length(self) -> float:
        return math.dist(self.start.pos, self.end.pos)


def parse_layer(description: str) -> str:
    if description.startswith("Durchsteckpad") or description.startswith("Via"):
        return "all"
    match = re.search(r" auf (F\.Cu|B\.Cu|PWR|GND|In1\.Cu|In2\.Cu)", description)
    if not match:
        raise RuntimeError(f"Cannot determine endpoint layer: {description}")
    return match.group(1)


def load_edges(report: Path) -> list[Edge]:
    data = json.loads(report.read_text(encoding="utf-8-sig"))
    result: list[Edge] = []
    for violation in data.get("unconnected_items", []):
        items = violation["items"]
        match = re.search(r"\[(/[^\]]+)\]", items[0]["description"])
        if not match:
            raise RuntimeError(f"Cannot determine net: {items[0]['description']}")
        net = match.group(1)
        endpoints = []
        for item in items:
            endpoints.append(
                Endpoint(
                    net=net,
                    pos=(float(item["pos"]["x"]), float(item["pos"]["y"])),
                    layer=parse_layer(item["description"]),
                    description=item["description"],
                )
            )
        result.append(Edge(net, endpoints[0], endpoints[1]))
    return result


class GridRouter:
    def __init__(
        self,
        board: pcbnew.BOARD,
        route_layer: int,
        step: float = GRID_STEP,
        block_in2_power_zones: bool = True,
    ) -> None:
        self.board = board
        self.route_layer = route_layer
        self.step = step
        self.block_in2_power_zones = block_in2_power_zones
        bbox = board.GetBoardEdgesBoundingBox()
        self.xmin = mm(bbox.GetX())
        self.ymin = mm(bbox.GetY())
        self.xmax = self.xmin + mm(bbox.GetWidth())
        self.ymax = self.ymin + mm(bbox.GetHeight())
        self.nx = int(math.ceil((self.xmax - self.xmin) / step)) + 1
        self.ny = int(math.ceil((self.ymax - self.ymin) / step)) + 1
        self.owners: dict[tuple[int, int], set[str]] = defaultdict(set)
        self.outline = pcbnew.SHAPE_POLY_SET()
        if not board.GetBoardPolygonOutlines(self.outline, False):
            raise RuntimeError("Could not build board outline")
        self._mark_boundaries_and_keepouts()
        self._mark_existing_route_copper()

    def index(self, p: tuple[float, float]) -> tuple[int, int]:
        return (
            int(round((p[0] - self.xmin) / self.step)),
            int(round((p[1] - self.ymin) / self.step)),
        )

    def coord(self, node: tuple[int, int]) -> tuple[float, float]:
        return self.xmin + node[0] * self.step, self.ymin + node[1] * self.step

    def _nodes_in_box(
        self, xmin: float, ymin: float, xmax: float, ymax: float
    ) -> list[tuple[int, int]]:
        ix0, iy0 = self.index((xmin, ymin))
        ix1, iy1 = self.index((xmax, ymax))
        return [
            (ix, iy)
            for ix in range(max(0, ix0 - 1), min(self.nx, ix1 + 2))
            for iy in range(max(0, iy0 - 1), min(self.ny, iy1 + 2))
        ]

    def _mark_boundaries_and_keepouts(self) -> None:
        edge_margin = 0.50
        for ix in range(self.nx):
            for iy in range(self.ny):
                p = self.coord((ix, iy))
                if (
                    p[0] < self.xmin + edge_margin
                    or p[0] > self.xmax - edge_margin
                    or p[1] < self.ymin + edge_margin
                    or p[1] > self.ymax - edge_margin
                    or not self.outline.PointInside(point(p))
                ):
                    self.owners[(ix, iy)].add("__BLOCK__")
        # PointInside rejects copper inside cut-outs, but it does not enforce
        # the configured copper-to-edge clearance around their boundary.  The
        # PocketLab card has a large rectangular lower-edge notch, so mark all
        # Edge.Cuts chords explicitly as clearance obstacles as well.
        edge_radius = edge_margin + TRACK_WIDTH / 2 + 0.03
        for drawing in self.board.GetDrawings():
            if drawing.GetLayer() != pcbnew.Edge_Cuts or not hasattr(drawing, "GetStart"):
                continue
            start = (mm(drawing.GetStart().x), mm(drawing.GetStart().y))
            end = (mm(drawing.GetEnd().x), mm(drawing.GetEnd().y))
            self.mark_segment(start, end, edge_radius, "__BLOCK__")
        rule_zones = [(zone, False) for zone in self.board.Zones()]
        for footprint in self.board.GetFootprints():
            rule_zones.extend((zone, True) for zone in footprint.Zones())
        for zone, footprint_embedded in rule_zones:
            if (
                zone.GetIsRuleArea()
                and (footprint_embedded or zone.IsOnLayer(self.route_layer))
                and (zone.GetDoNotAllowTracks() or zone.GetDoNotAllowVias())
            ):
                box = zone.GetBoundingBox()
                inflate = TRACK_WIDTH / 2 + CLEARANCE + 0.05
                self.mark_box(
                    mm(box.GetX()) - inflate,
                    mm(box.GetY()) - inflate,
                    mm(box.GetRight()) + inflate,
                    mm(box.GetBottom()) + inflate,
                    "__BLOCK__",
                )

        for zone in (
            self.board.Zones()
            if self.route_layer == pcbnew.In2_Cu and self.block_in2_power_zones
            else ()
        ):
            if (
                zone.GetNetname() not in {"/+5V_RAW", "/+5V_AUX"}
                or not zone.HasFilledPolysForLayer(pcbnew.In2_Cu)
            ):
                continue
            polygons = zone.GetFilledPolysList(pcbnew.In2_Cu)
            box = polygons.BBox()
            for node in self._nodes_in_box(
                mm(box.GetX()),
                mm(box.GetY()),
                mm(box.GetRight()),
                mm(box.GetBottom()),
            ):
                if polygons.PointInside(point(self.coord(node))):
                    self.owners[node].add("__BLOCK__")

    def mark_circle(
        self, center: tuple[float, float], radius: float, owner: str
    ) -> None:
        for node in self._nodes_in_box(
            center[0] - radius,
            center[1] - radius,
            center[0] + radius,
            center[1] + radius,
        ):
            if math.dist(self.coord(node), center) <= radius:
                self.owners[node].add(owner)

    def mark_box(
        self, xmin: float, ymin: float, xmax: float, ymax: float, owner: str
    ) -> None:
        for node in self._nodes_in_box(xmin, ymin, xmax, ymax):
            x, y = self.coord(node)
            if xmin <= x <= xmax and ymin <= y <= ymax:
                self.owners[node].add(owner)

    def mark_segment(
        self,
        start: tuple[float, float],
        end: tuple[float, float],
        radius: float,
        owner: str,
    ) -> None:
        for node in self._nodes_in_box(
            min(start[0], end[0]) - radius,
            min(start[1], end[1]) - radius,
            max(start[0], end[0]) + radius,
            max(start[1], end[1]) + radius,
        ):
            if distance_to_segment(self.coord(node), start, end) <= radius:
                self.owners[node].add(owner)

    def _mark_existing_route_copper(self) -> None:
        track_radius = TRACK_WIDTH / 2 + CLEARANCE
        for footprint in self.board.GetFootprints():
            for pad in footprint.Pads():
                if not pad.IsOnLayer(self.route_layer):
                    continue
                box = pad.GetBoundingBox()
                inflate = TRACK_WIDTH / 2 + CLEARANCE
                self.mark_box(
                    mm(box.GetX()) - inflate,
                    mm(box.GetY()) - inflate,
                    mm(box.GetRight()) + inflate,
                    mm(box.GetBottom()) + inflate,
                    pad.GetNetname() or "__BLOCK__",
                )
        for item in self.board.GetTracks():
            owner = item.GetNetname() or "__BLOCK__"
            if isinstance(item, pcbnew.PCB_VIA):
                if item.IsOnLayer(self.route_layer):
                    center = (mm(item.GetPosition().x), mm(item.GetPosition().y))
                    radius = mm(item.GetWidth(self.route_layer)) / 2 + track_radius
                    self.mark_circle(center, radius, owner)
            elif item.GetLayer() == self.route_layer:
                start = (mm(item.GetStart().x), mm(item.GetStart().y))
                end = (mm(item.GetEnd().x), mm(item.GetEnd().y))
                radius = mm(item.GetWidth()) / 2 + track_radius
                self.mark_segment(start, end, radius, owner)

    def is_free(self, node: tuple[int, int], net: str) -> bool:
        if not (0 <= node[0] < self.nx and 0 <= node[1] < self.ny):
            return False
        return not (self.owners.get(node, set()) - {net})

    def circle_is_free(
        self, center: tuple[float, float], radius: float, net: str
    ) -> bool:
        for node in self._nodes_in_box(
            center[0] - radius,
            center[1] - radius,
            center[0] + radius,
            center[1] + radius,
        ):
            if math.dist(self.coord(node), center) <= radius and not self.is_free(
                node, net
            ):
                return False
        return True

    def nearest_free_node(
        self, position: tuple[float, float], net: str
    ) -> tuple[int, int]:
        center = self.index(position)
        candidates = []
        for radius in range(12):
            for dx in range(-radius, radius + 1):
                for dy in range(-radius, radius + 1):
                    node = center[0] + dx, center[1] + dy
                    if self.is_free(node, net):
                        candidates.append((math.dist(position, self.coord(node)), node))
            if candidates:
                return min(candidates)[1]
        raise RuntimeError(f"No free grid access for {net}: {position}")

    def route(
        self, start: tuple[float, float], end: tuple[float, float], net: str
    ) -> list[tuple[float, float]]:
        source = self.nearest_free_node(start, net)
        target = self.nearest_free_node(end, net)
        directions = (
            (1, 0),
            (-1, 0),
            (0, 1),
            (0, -1),
            (1, 1),
            (1, -1),
            (-1, 1),
            (-1, -1),
        )
        queue: list[tuple[float, float, tuple[int, int], tuple[int, int]]] = []
        initial_dir = (0, 0)
        heapq.heappush(queue, (0.0, 0.0, source, initial_dir))
        best = {(source, initial_dir): 0.0}
        parent: dict[
            tuple[tuple[int, int], tuple[int, int]],
            tuple[tuple[int, int], tuple[int, int]],
        ] = {}
        found: tuple[tuple[int, int], tuple[int, int]] | None = None
        while queue:
            _, cost, node, previous_dir = heapq.heappop(queue)
            state = (node, previous_dir)
            if cost != best.get(state):
                continue
            if node == target:
                found = state
                break
            for direction in directions:
                nxt = node[0] + direction[0], node[1] + direction[1]
                if not self.is_free(nxt, net):
                    continue
                move = math.sqrt(2.0) if direction[0] and direction[1] else 1.0
                turn = 0.0 if previous_dir in ((0, 0), direction) else 0.18
                new_cost = cost + move + turn
                new_state = (nxt, direction)
                if new_cost >= best.get(new_state, math.inf):
                    continue
                best[new_state] = new_cost
                parent[new_state] = state
                dx, dy = target[0] - nxt[0], target[1] - nxt[1]
                heuristic = max(abs(dx), abs(dy)) + (math.sqrt(2) - 1) * min(
                    abs(dx), abs(dy)
                )
                heapq.heappush(
                    queue, (new_cost + heuristic, new_cost, nxt, direction)
                )
        if found is None:
            layer_name = self.board.GetLayerName(self.route_layer)
            raise RuntimeError(
                f"No {layer_name} grid path for {net}: {start} -> {end}"
            )
        nodes = []
        state = found
        while True:
            nodes.append(state[0])
            if state[0] == source and state[1] == initial_dir:
                break
            state = parent[state]
        nodes.reverse()
        compressed = [nodes[0]]
        previous = None
        for a, b in zip(nodes, nodes[1:]):
            direction = (b[0] - a[0], b[1] - a[1])
            if previous is not None and direction != previous:
                compressed.append(a)
            previous = direction
        compressed.append(nodes[-1])
        points = [start]
        points.extend(self.coord(node) for node in compressed[1:-1])
        points.append(end)
        for a, b in zip(points, points[1:]):
            self.mark_segment(
                a,
                b,
                TRACK_WIDTH / 2 + CLEARANCE + TRACK_WIDTH / 2 + 0.05,
                net,
            )
        return points


def add_track(
    board: pcbnew.BOARD,
    net: str,
    start: tuple[float, float],
    end: tuple[float, float],
    layer: int,
    width: float = TRACK_WIDTH,
) -> None:
    if start == end:
        return
    track = pcbnew.PCB_TRACK(board)
    track.SetStart(point(start))
    track.SetEnd(point(end))
    track.SetWidth(iu(width))
    track.SetLayer(layer)
    track.SetNet(board.FindNet(net))
    track.SetLocked(True)
    board.Add(track)


def add_via(
    board: pcbnew.BOARD,
    net: str,
    pos: tuple[float, float],
    via_type: int,
    layers: tuple[int, int],
    diameter: float,
    drill: float,
) -> None:
    via = pcbnew.PCB_VIA(board)
    via.SetPosition(point(pos))
    via.SetViaType(via_type)
    via.SetWidth(iu(diameter))
    via.SetDrill(iu(drill))
    via.SetLayerPair(*layers)
    via.SetNet(board.FindNet(net))
    via.SetLocked(True)
    board.Add(via)


def segment_clear_on_layer(
    board: pcbnew.BOARD,
    layer: int,
    net: str,
    start: tuple[float, float],
    end: tuple[float, float],
    item_radius: float = TRACK_WIDTH / 2,
) -> bool:
    required = item_radius + CLEARANCE
    length = math.dist(start, end)
    samples = max(1, int(math.ceil(length / 0.10)))
    for footprint in board.GetFootprints():
        for pad in footprint.Pads():
            if not pad.IsOnLayer(layer) or pad.GetNetname() == net:
                continue
            box = pad.GetBoundingBox()
            xmin, ymin = mm(box.GetX()), mm(box.GetY())
            xmax, ymax = mm(box.GetRight()), mm(box.GetBottom())
            for index in range(samples + 1):
                fraction = index / samples
                x = start[0] + fraction * (end[0] - start[0])
                y = start[1] + fraction * (end[1] - start[1])
                dx = max(xmin - x, 0.0, x - xmax)
                dy = max(ymin - y, 0.0, y - ymax)
                if math.hypot(dx, dy) < required:
                    return False
    for item in board.GetTracks():
        if item.GetNetname() == net:
            continue
        if isinstance(item, pcbnew.PCB_VIA):
            if item.IsOnLayer(layer):
                center = (mm(item.GetPosition().x), mm(item.GetPosition().y))
                radius = mm(item.GetWidth(layer)) / 2 + required
                if distance_to_segment(center, start, end) < radius:
                    return False
        elif item.GetLayer() == layer:
            other_start = (mm(item.GetStart().x), mm(item.GetStart().y))
            other_end = (mm(item.GetEnd().x), mm(item.GetEnd().y))
            if segment_distance(start, end, other_start, other_end) < (
                mm(item.GetWidth()) / 2 + required
            ):
                return False
    return True


def same_net_track_sites(
    board: pcbnew.BOARD,
    endpoint: Endpoint,
    layer: int,
) -> tuple[tuple[float, float], ...]:
    """Return nearby points on the DRC endpoint's same-net copper branch.

    KiCad often reports the nearest end of a very short existing track as the
    second item of an open connection.  That exact point can be too cramped
    for a via even though another point on the same copper branch is legal.
    """
    if not endpoint.description.startswith(("Leiterbahn", "Track")):
        return ()
    candidates: list[tuple[float, tuple[float, float]]] = []
    for item in board.GetTracks():
        if isinstance(item, pcbnew.PCB_VIA):
            continue
        if item.GetLayer() != layer or item.GetNetname() != endpoint.net:
            continue
        start = (mm(item.GetStart().x), mm(item.GetStart().y))
        end = (mm(item.GetEnd().x), mm(item.GetEnd().y))
        for fraction in (0.0, 0.25, 0.5, 0.75, 1.0):
            site = (
                start[0] + fraction * (end[0] - start[0]),
                start[1] + fraction * (end[1] - start[1]),
            )
            candidates.append((math.dist(endpoint.pos, site), site))
    result: list[tuple[float, float]] = []
    seen: set[tuple[int, int]] = set()
    for _, site in sorted(candidates):
        key = (round(site[0] * 1000), round(site[1] * 1000))
        if key in seen:
            continue
        seen.add(key)
        result.append(site)
    return tuple(result)


def nearby_existing_via_site(
    board: pcbnew.BOARD,
    endpoint: Endpoint,
    route_layer: int,
) -> tuple[float, float] | None:
    if not endpoint.description.startswith(("Leiterbahn", "Track")):
        return None
    candidates: list[tuple[float, tuple[float, float]]] = []
    for item in board.GetTracks():
        if not isinstance(item, pcbnew.PCB_VIA):
            continue
        spans_route_layer = (
            item.GetViaType() == pcbnew.VIATYPE_THROUGH or item.IsOnLayer(route_layer)
        )
        if item.GetNetname() != endpoint.net or not spans_route_layer:
            continue
        site = (mm(item.GetPosition().x), mm(item.GetPosition().y))
        separation = math.dist(endpoint.pos, site)
        if separation <= 1.25:
            candidates.append((separation, site))
    return min(candidates)[1] if candidates else None
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

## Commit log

2026-08-30 Reduce inner-layer routing conflicts
    [PocketLab-Card-routing-working.kicad_pcb]
2026-08-30 Improve battery enable and GPIO layer routing
    [PocketLab-Card-routing-working.kicad_pcb]
2026-08-30 Reduce routing conflicts around power and control nets
    [PocketLab-Card-routing-working.kicad_pcb]
2026-08-30 Close final ground island and reduce inner-layer conflicts
    [PocketLab-Card-routing-working.kicad_pcb]
2026-08-30 Reduce major hole-clearance routing clusters
    [PocketLab-Card-routing-working.kicad_pcb]
2026-08-30 Reroute additional inner-layer hole conflicts
    [PocketLab-Card-routing-working.kicad_pcb]
2026-08-30 Resolve SPI overlap and reroute GPIO8
    [PocketLab-Card-routing-working.kicad_pcb]
2026-08-30 Reroute inner signals around drill conflicts
    [PocketLab-Card-routing-working.kicad_pcb]
2026-08-30 Route additional drill-clearance offenders
    [PocketLab-Card-routing-working.kicad_pcb]
2026-08-30 Reduce NFC and SD drill conflicts
    [PocketLab-Card-routing-working.kicad_pcb]
2026-08-30 Reroute auxiliary and expansion signals
    [PocketLab-Card-routing-working.kicad_pcb]
2026-08-30 Reduce GPIO and low frequency drill conflicts
    [PocketLab-Card-routing-working.kicad_pcb]
2026-08-30 Reroute GPIO and NFC drill offenders
    [PocketLab-Card-routing-working.kicad_pcb]
2026-08-30 Reduce sensor and low frequency drill conflicts
    [PocketLab-Card-routing-working.kicad_pcb]
2026-08-30 Checkpoint OLED-free routing before restoring OLED design
    [PocketLab-Card-routing-working.kicad_pcb]
2026-08-30 Restore OLED board and close all remaining connections
    [PocketLab-Card.kicad_pcb]
2026-08-30 Replace duplicate OLED routing via stacks
    [PocketLab-Card.kicad_pcb]
2026-08-30 Reduce OLED routing drill conflicts
    [PocketLab-Card.kicad_pcb]
2026-08-30 Relocate clustered OLED routing vias
    [PocketLab-Card.kicad_pcb]
2026-08-30 Move OLED I2C routing away from drill conflicts
    [PocketLab-Card.kicad_pcb]
2026-08-30 Clear OLED routing drill violations
    [PocketLab-Card.kicad_pcb]
2026-08-30 Relocate congested routing vias
    [PocketLab-Card.kicad_pcb]
2026-08-30 Relieve additional via routing conflicts
    [PocketLab-Card.kicad_pcb]
2026-09-16 Publish current routing checkpoint and 3D viewer
    [PocketLab-Card.kicad_pcb, PocketLab-Card.kicad_sch]
